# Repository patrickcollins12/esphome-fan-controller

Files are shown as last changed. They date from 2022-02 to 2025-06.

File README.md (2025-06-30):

# ESPHome Fan Controller

This project describes how to build a whisper quiet thermostat-controlled fan for cooling your media console, gaming cupboard or that dying star in your networking cabinet.

The software is ESPHome and Home Assistant. The hardware is an ESP32 with a regular 12v 120mm Computer Fan (PWM) and a Temperature Sensor (DHT11).

## Cost
The electronic parts are $29 USD including the ESP32. You will also need a multimeter.

## Motivation
My sons's Playstation 5 sits in our TV Console which runs hotter than Sol. Also in that Media Console is a Macmini, a Raspberry Pi and a few other devices. My wife likes to keep the door neat and closed, so it needs some cooling!

I used to have a thermostat that mindlessly flipped the fan on and off whenever the temperature crossed a threshold. Not great, the fan cycling was a mood killer on movie nights and dismally failed wife approval. Enter this smart thermostat: instead of brute-force toggling, it smoothly adjusts the 12V fan speed to maintain the perfect temperature. It’ll settle on just the right power level (say, 22% power) to keep things cool without the unnecessary drama.

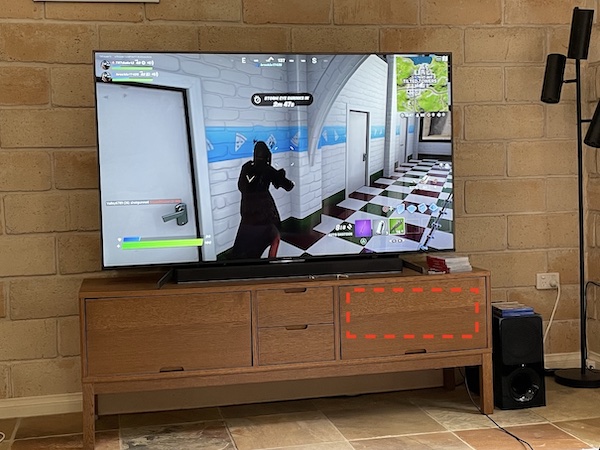
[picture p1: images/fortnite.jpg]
"closed cabinet"


## Features
The main features are:

- the **fan dynamically adjusts** it's speed based on the temperature sensor using a Process Control mechanism called PID
- **adjustable target temperature**. I currently target 30degC but maybe in winter I'll reduce it to 27.
- uses ESP32's Wifi to connect to Home Assistant for control and reporting
- the ESP32 is standalone and so the cooling function will continue to operate without Wifi. Doesn't need HomeAssistant or Wifi to operate. Wifi is only needed for setup, manual control and reporting.
- **no screen** is needed on the device itself, all management is done via Home Assistant
- my system uses two fans for extra cooling. Depending on how much air you need to draw through your enclosed space you could use 1, 2, 4, 10 .. n fans.
- one esp32 can control up to 10 independent enclosures each with separate temperature sensors and fans. You're only limited by the Amps of your 12v Power Bricks and the 10 pwm pins on your ESP32.
- **manual speed control** over ride if you don't want to use PID Control
- **no coding is needed**. Just some configuration in YAML files. In fact this repo only contains 1 file ``config-fan.yaml``.
- **No resistors, capacitors or difficult soldering needed**. The fan and the temperature sensor plug straight onto the pins of the ESP32. Although I did solder mount mine on a perfboard for cleanliness and put it in a case.

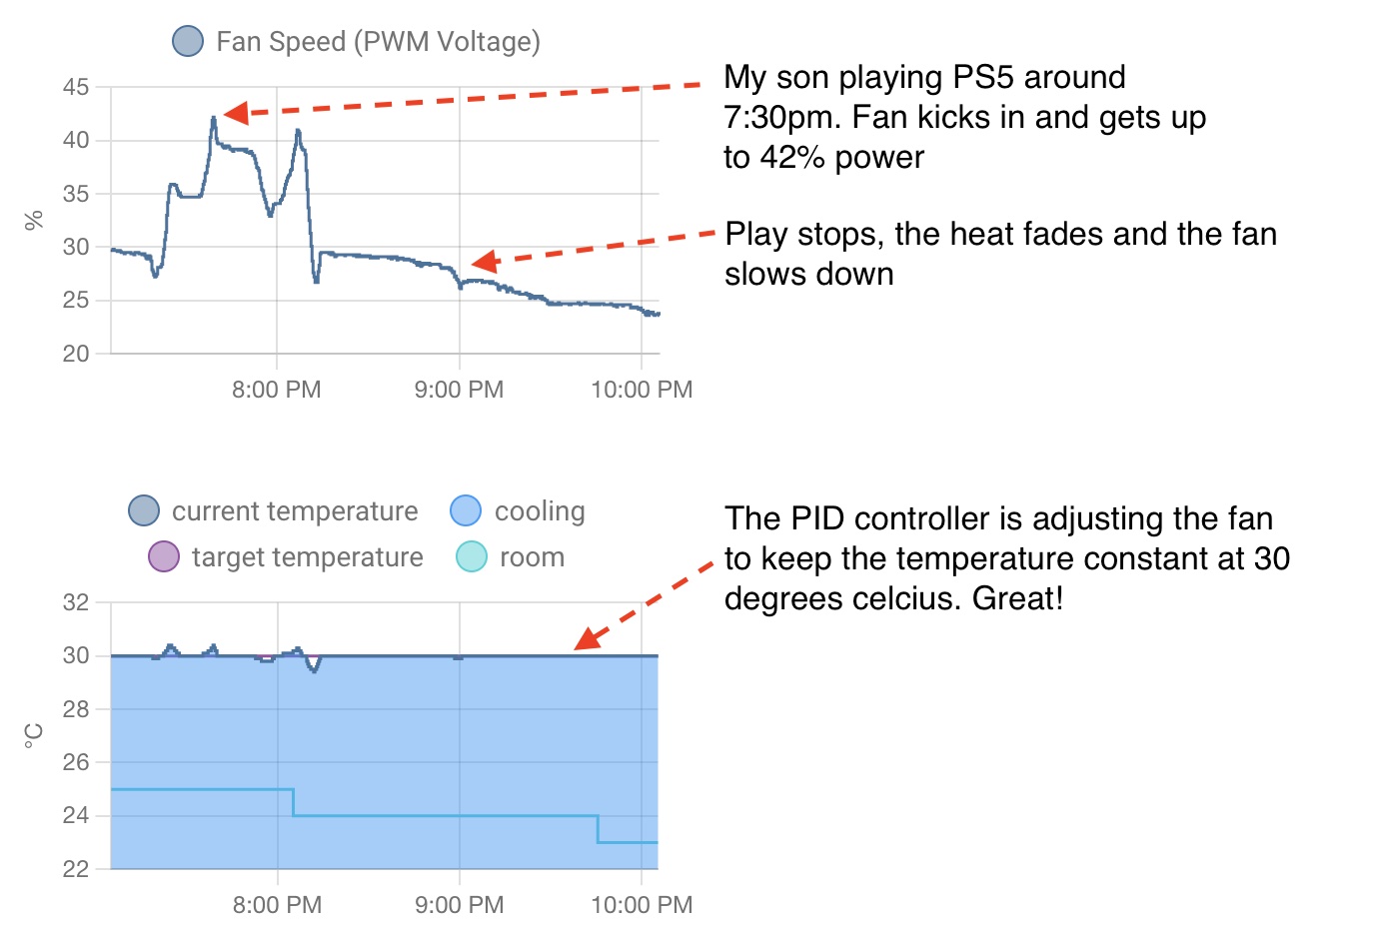
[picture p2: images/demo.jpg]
"graphs"


This is a screenshot from Home Assistant. I'll show you how to setup this dashboard.

## Visuals
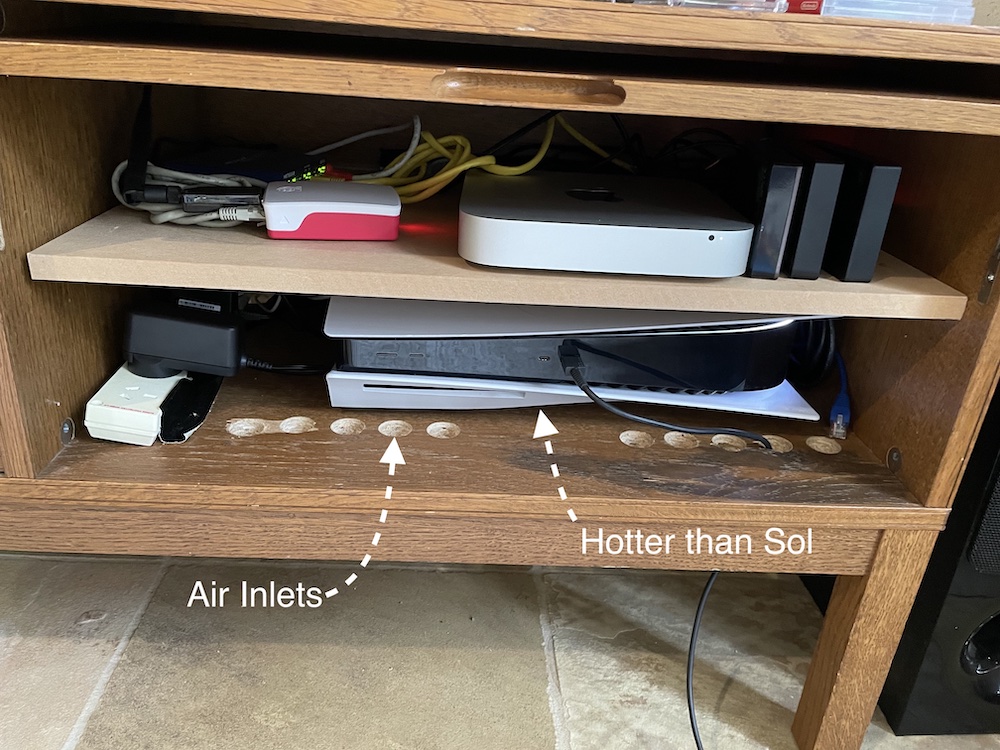
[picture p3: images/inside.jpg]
"inside cabinet"

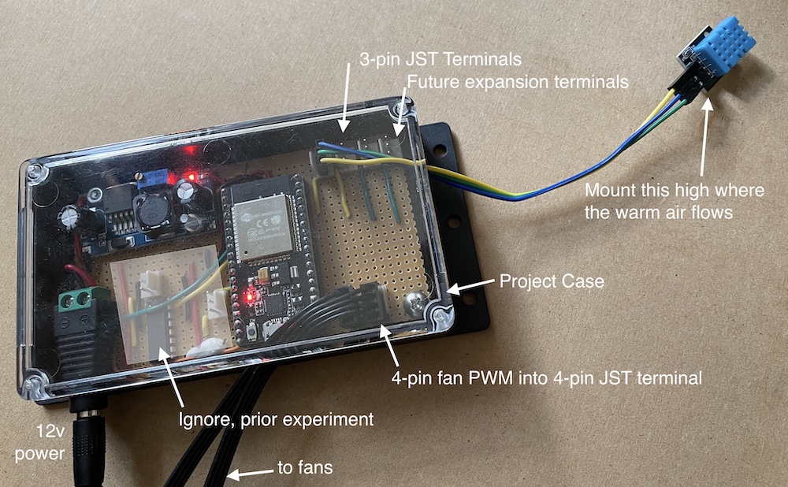
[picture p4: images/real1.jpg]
"controller"

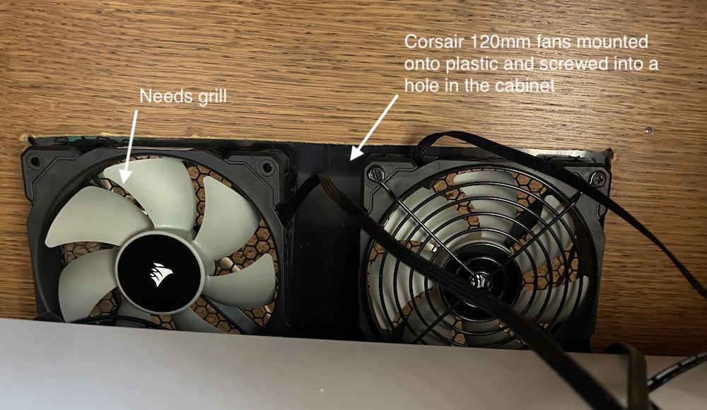
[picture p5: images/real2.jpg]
"fans"


## Examples from other users
https://github.com/patrickcollins12/esphome-fan-controller/issues/34

## Parts (~$29 USD)

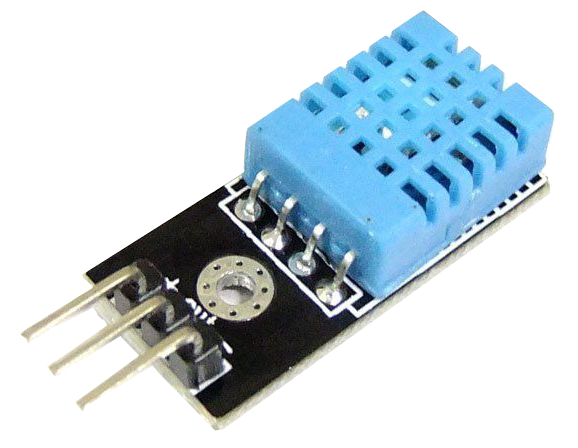
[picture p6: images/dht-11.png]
- **DHT11** - temperature and humidity sensor. I'm using the one on a board with 3-pins. Cost $0.20 USD<br>

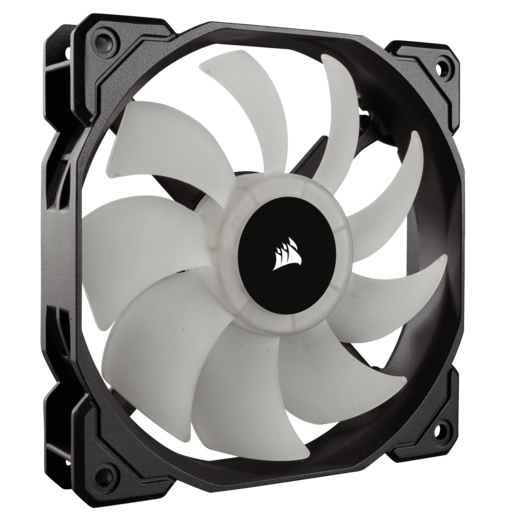
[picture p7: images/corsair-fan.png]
- **12v PWM 4-pin Computer Fan** - I'm using 2 x [120mm Corsair fans](https://www.corsair.com/us/en/Categories/Products/Fans/Magnetic-Levitation-Fans/ml-config/p/CO-9050039-WW). Any 12v PWM-controllable fan should work. Cost $8-$15 USD. I recommend getting high quality fans if you care about noise and need to move a lot of air<br>. 

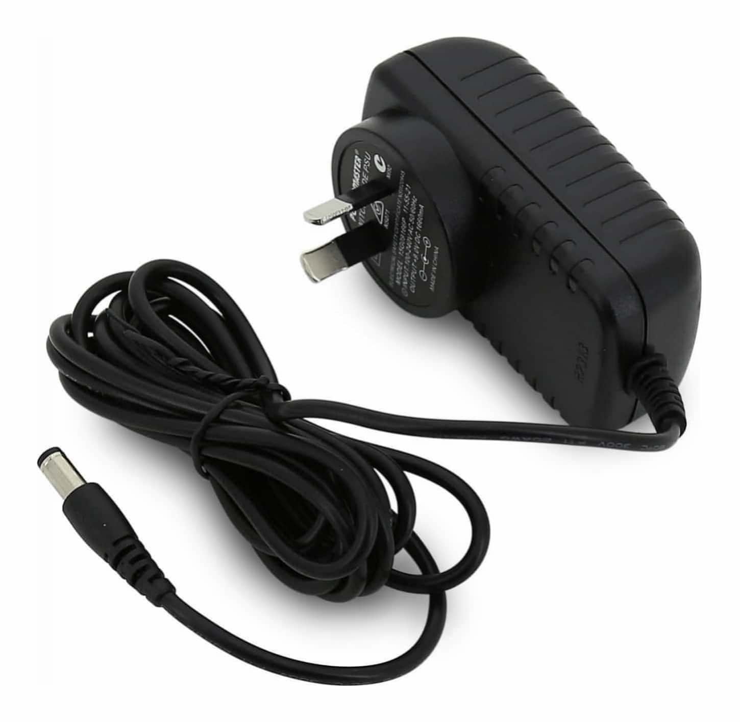
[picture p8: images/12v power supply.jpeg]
- **12v Power Adapter** - 1A or 2A should be fine depending on your fan's current draw. Cost $7 <br> 

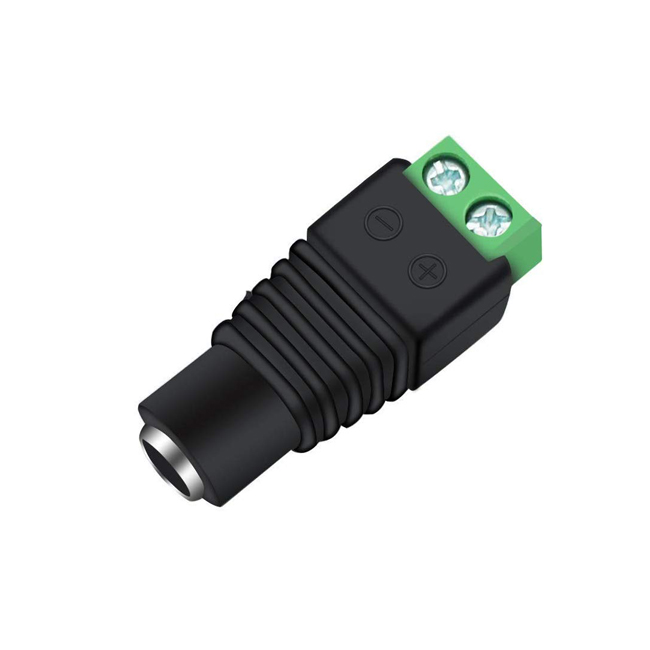
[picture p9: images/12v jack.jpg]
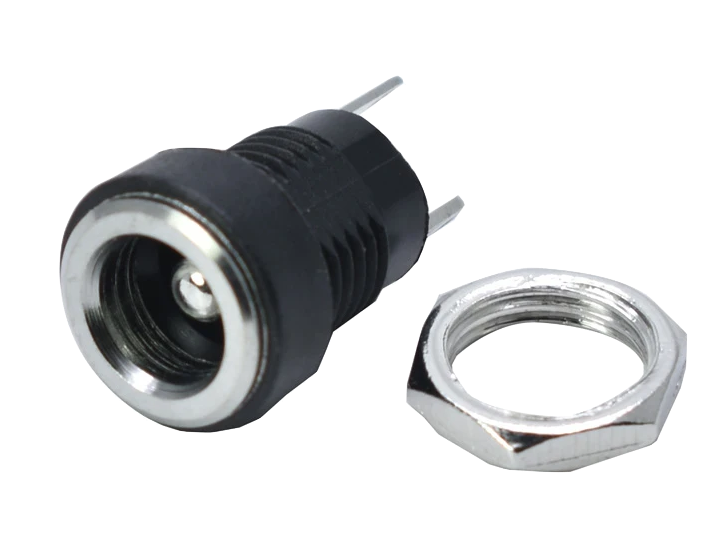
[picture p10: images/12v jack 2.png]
- **12v DC Female Jack** - with wire outlets. You can normally buy these with the Power Adapter<br> or  

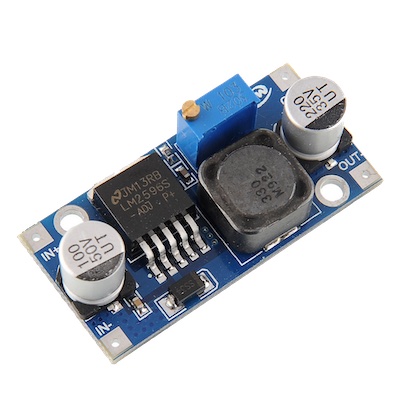
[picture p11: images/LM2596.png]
- **LM2596 Buck Converter** - to convert 12v down to 3.3v. Cost $0.21 each (normally in packs of 6-10)<br> 

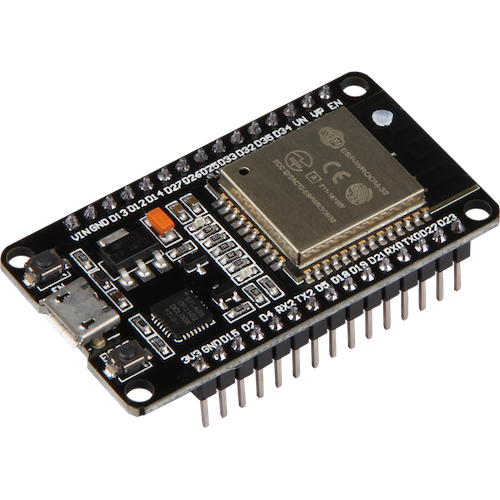
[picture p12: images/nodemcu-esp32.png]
- **ESP32**. You can use any ESP32. I'm using a NodeMCU compatible board. Mine cost $1.50 USD from Aliexpress. Note it [will also work on a Raspberry Pi Pico W](https://github.com/patrickcollins12/esphome-fan-controller/discussions/50).<br> 

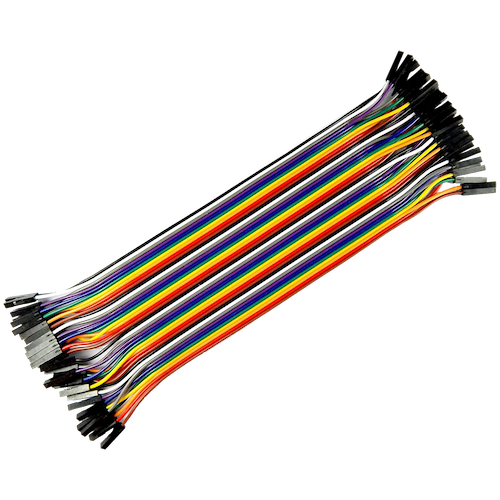
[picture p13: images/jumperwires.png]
- **Jumper wires**. Some jumper wires to connect the ESP32 to the various parts here. $1. <br>

You will also need a multimeter to adjust the output of the buck converter. Optionally, if you want to move this beyond a prototype you will need some soldering equipment and a 3d printer for a case or to buy a housing.

## Choosing a Good Fan
You need a 4-pin fan which has PWM. 3-pin fans aren't acceptable, they are just on/off with tachometer sensor.

As you'll see below, our fans are being powered by the PWM pin. Our expectation is that the fans stop spinning at 0% power. Some people have reported that some fans don't stop running at 0% power (or worse that they stop completely at 100% power which is weird). 

It appears that Corsair and Noctua fans behave as expected so you might want to stick with them.

However, if your fan does behave this way, you can use a MOSFET to turn it off. There are ([instructions here for how to do this](https://github.com/patrickcollins12/esphome-fan-controller/issues/17#issuecomment-1557136383)). Please post your progress to that issue.

## Wiring Diagram
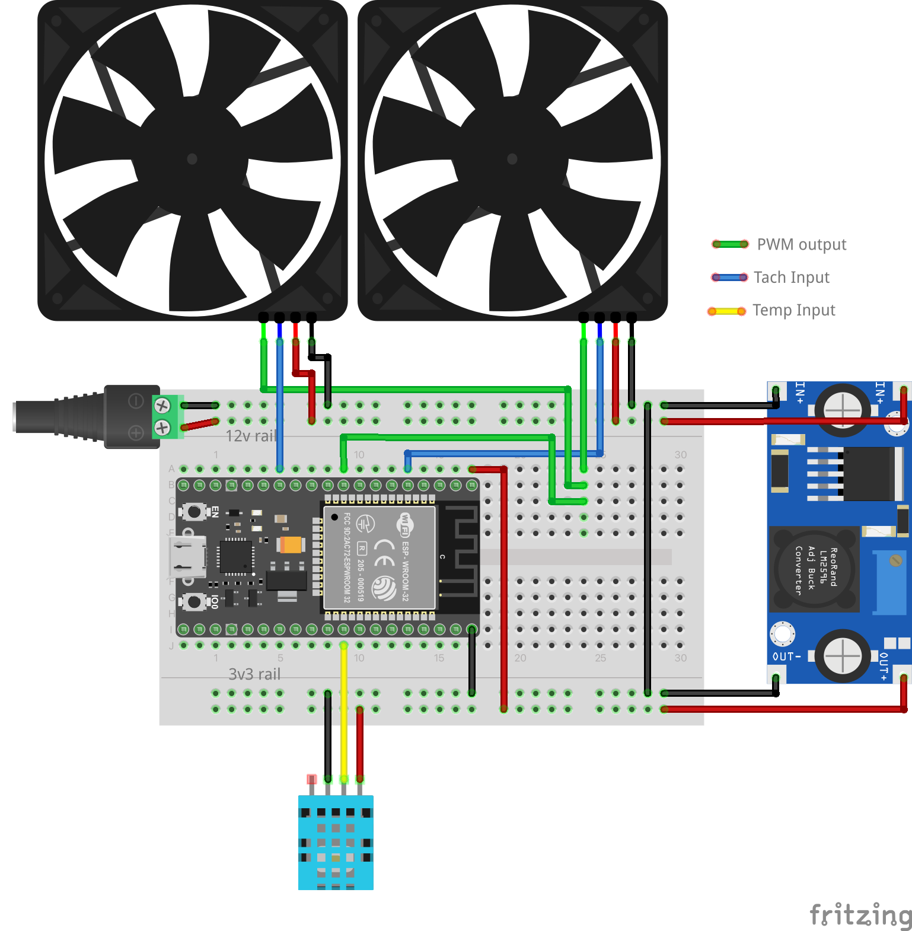
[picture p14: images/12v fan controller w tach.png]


Some important notes:
- connect the fan PWM pin to a PWM GPIO
- turn the knob on the buck converter with a screwdriver to make it output exactly 3.3v. You'll need a multimeter to measure that output.
- ensure the 12v and 3.3v grounds are connected together.
- the Blue line is the tachometer ("Tach") input pin. It is optional to connect this. You can connect this to a PWM input pin of your choice (GPIO25 in the example config) and it will send 1-2 pulses per full turn (depending on the fan). You can use this to monitor actual RPM of the fan and detect a fan defect, blocked rotor, etc. You will need one PWM input for each tach on each fan.
- you could easily skip the Buck converter and use two separate power sources 3.3v and 12v. 
- the fritzing diagram shows a 4-pin DHT-11, when in fact I have the simpler 3-pin version as shown in the parts list. The 4-pin version might need a pullup resistor, haven't tried it.

## Common Wiring Error - not joining grounds 

NOTE: if you don't join your 3.3v and 12v ground wires together your fan will keep spinning. At least 5 different builds have reported this issue. 

## Installing the software onto the ESP32

### Get this repo
Clone this github repository.
From the command line and then cd into the directory

```
git clone https://github.com/patrickcollins12/esphome-fan-controller.git
cd esphome-fan-controller
```

### Review the YAML and read the ESPHome docs.

Review the YAML file.

Ensure the pins are set correctly for the PWM Fan (ledc) and the DHT-11.

Review the instructions for [the ESPHome Climate Thermostat](https://esphome.io/components/climate/index.html), [ESPHome PID Climate Thermostat](https://esphome.io/components/climate/pid.html) and the [DHT-11 sensor](https://esphome.io/components/sensor/dht.html).

Change the device name from ``console-fan`` to whatever seems appropriate. You might want to change the yaml filename as well.

If you want to use a Raspberry Pi Pico instead of an ESP32, change the board and platform as well [according to this discussion](https://github.com/patrickcollins12/esphome-fan-controller/discussions/50).

### Setup your temperature sensor

Set the correct pin for your temp sensor. Note that the DHT11 sensor is setup to use an exponential moving average. Without this filter the PID controller reacts to every minor sensor movement. If you have a faster sensor like the BME260 you might need to tweak this filter.

```yaml
  # GET TEMP/HUMIDITY FROM DHT11
  - platform: dht
    pin: GPIO33
    temperature:
      name: "Temperature"
      id: console_fan_temperature
      accuracy_decimals: 3

      # If you don't smooth the temperature readings 
      # the PID controller over reacts to small changes.
      filters:
         - exponential_moving_average:  
             alpha: 0.1
             send_every: 1

```

(Some people [take an average of two temperature sensors](https://github.com/patrickcollins12/esphome-fan-controller/issues/5).)

### Setup your PWM fan

Make sure you connect your fan to a PWM capable GPIO. All ESP32 pins that can act as outputs can be used as PWM pins but GPIOs 34-39 can’t generate PWM.

Also note that my fans stop spinning below 13% power, so I set that as the minimum. I have a max power of 80% applied to the fans to make them wife-friendly. You might want to remove this minimum or maximum. 

```yaml
  - platform: ledc
    id: console_heat_speed
    pin: GPIO27

    # 25KHz is standard PWM PC fan frequency, minimises buzzing
    frequency: "25000 Hz"

    min_power: 13%
    max_power: 80%

```

### Setup your wifi details

``mv secrets-sample.yaml secrets.yaml``

Edit your wifi credentials in secrets.yaml. The .gitignore will prevent you accidentally uploading your wifi credentials to github.

### Install ESPHome

[Install ESPHome](https://esphome.io/guides/installing_esphome.html) according to the instructions on the ESPHome website.

I prefer command-line on Mac:
``pip3 install esphome``

Most people use the ESPHome that runs inside Home Assistant. You can use that too.

### Install to ESP32

Connect your ESP32 via USB to your computer, then upload the Firmware to the ESP32.

`` esphome run console-fan.yaml``

At this time if you've set the pins right, the sensor should be spitting out values and the PID can control the fan.

Success! 

```
% esphome logs console-fan.yaml
INFO Reading configuration console-fan.yaml...
INFO Starting log output from console-fan.local using esphome API
INFO Successfully connected to console-fan.local
...
[22:54:09][C][mdns:085]:   Hostname: console-fan
[22:54:09][C][homeassistant.text_sensor:023]: Homeassistant Text Sensor 'ha_kp'
[22:54:09][C][homeassistant.text_sensor:024]:   Entity ID: 'input_text.kp'
[22:54:10][C][homeassistant.text_sensor:023]: Homeassistant Text Sensor 'ha_ki'
[22:54:10][C][homeassistant.text_sensor:024]:   Entity ID: 'input_text.ki'
[22:54:10][C][homeassistant.text_sensor:023]: Homeassistant Text Sensor 'ha_kd'
[22:54:10][C][homeassistant.text_sensor:024]:   Entity ID: 'input_text.kd'
[22:54:10][D][dht:048]: Got Temperature=30.0°C Humidity=38.0%
[22:54:10][D][sensor:113]: 'Humidity': Sending state 38.00000 % with 0 decimals of accuracy
[22:54:11][D][dht:048]: Got Temperature=30.0°C Humidity=38.0%
[22:54:11][D][sensor:113]: 'Humidity': Sending state 38.00000 % with 0 decimals of accuracy
[22:54:12][D][dht:048]: Got Temperature=30.0°C Humidity=38.0%
[22:54:12][D][sensor:113]: 'Humidity': Sending state 38.00000 % with 0 decimals of accuracy
```

## Setup Home Assistant

If the above steps worked correctly, the device will be auto-discovered by Home Assistant. You will need to add the device.

Multiple sensors and switches are exposed by the ESPHome software.

You also need to setup the dashboard. I'll explain those two steps below.

## Setting up the Home Assistant Dashboard

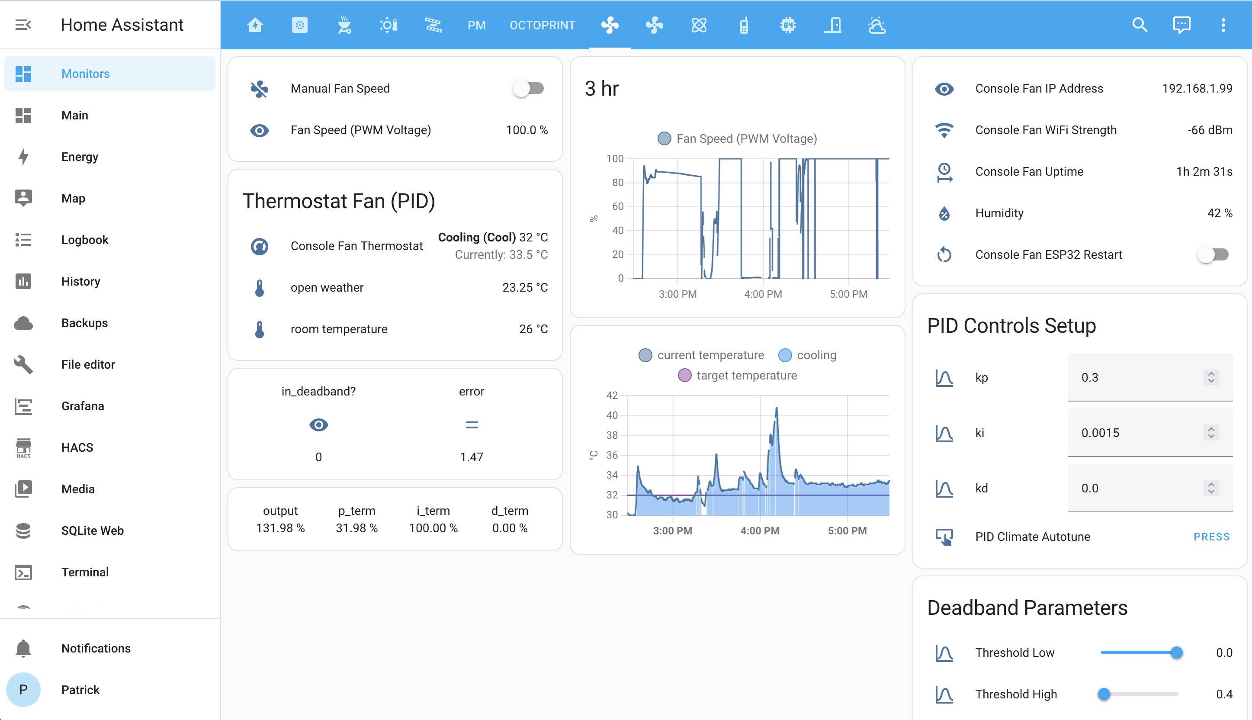
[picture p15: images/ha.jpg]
dashboard


Here is my full dashboard in Home Assistant.

For this full dashboard configuration, checkout ```lovelace-dashboard.yaml```

Let's go through this page section-by-section.

### The Primary Controls

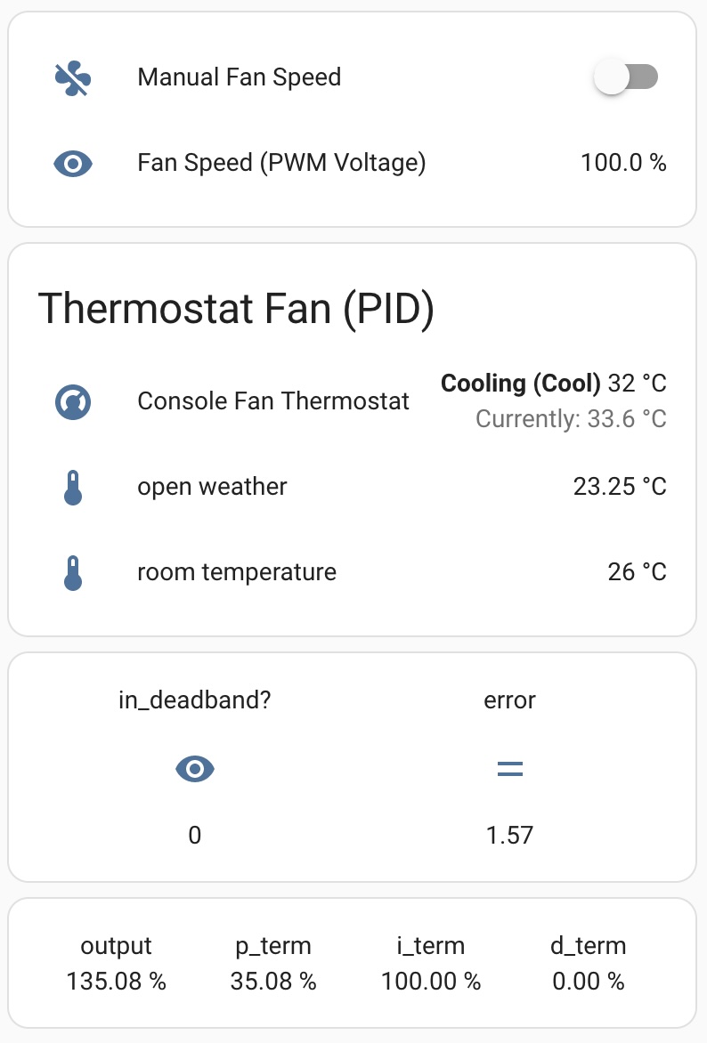
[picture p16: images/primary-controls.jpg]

 
```yaml
type: entities
entities:
  - entity: fan.manual_fan_speed
  - entity: sensor.fan_speed_pwm_voltage
```

- You can turn on  `manual fan speed` and use this fan control to adjust the speed manually. 

- The ``Fan Speed (PWM Voltage)`` is the % of voltage being sent out via PWM to the fan controller. At 100% it will be sending 12v, at 50% it will be sending 6v.

If `manual fan speed` is off, this next card stack will conditionally display.

```yaml
type: conditional
conditions:
  - condition: state
    entity: fan.manual_fan_speed
    state_not: 'on'
card:
  type: vertical-stack
  cards:
    - type: entities
      title: Thermostat Fan (PID)
      entities:
        - entity: climate.console_fan_thermostat
        - entity: sensor.openweathermap_temperature
          name: open weather
        - entity: sensor.contact_sensor_1_device_temperature
          name: room temperature
    - type: vertical-stack
      cards:
        - type: glance
          entities:
            - entity: sensor.console_fan_is_in_deadband
              name: in_deadband?
            - entity: sensor.console_fan_error_value
              name: error
              icon: mdi:equal
        - type: glance
          show_icon: false
          entities:
            - entity: sensor.console_fan_output_value
              name: output
            - entity: sensor.console_fan_p_term
              name: p_term
            - entity: sensor.console_fan_i_term
              name: i_term
            - entity: sensor.console_fan_d_term
              name: d_term
```

- The `Console Fan Thermostat` is a controllable thermostat, by clicking it you can alter the target temperature and turn the fan on/off. These changes will be persisted to flash on the ESP32.

- The `Open Weather` and `Room` temperatures are from other sensors in my house for reference.

- The ``kp, ki and kd`` inputs are exposed from the device. Your ESP32 will be automatically receiving changes to these values to control the behavior of the PID controller. While you could tune these from the config.yaml it requires a compile, upload and reboot cycle each time. This is inconvenient and best to tweak in real-time. We want to expose these 3 parameters to a Home Assistant dashboard.

### The Graphs

Add the fan speed and the thermostat to two separate graphs. I've also added my room temperature from a separate device for comparison.

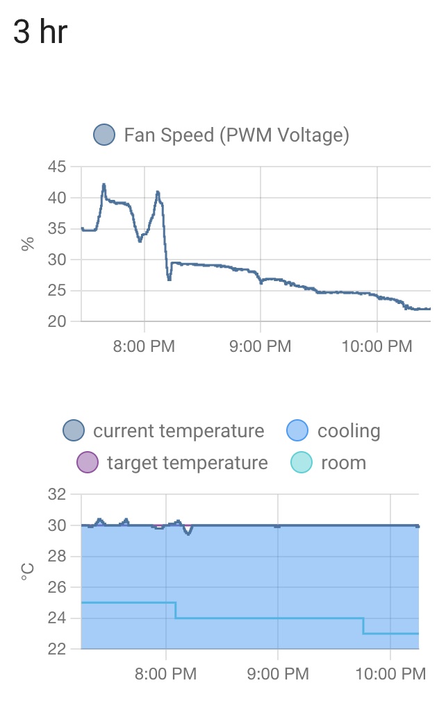
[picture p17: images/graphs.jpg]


```yaml
type: vertical-stack
title: 3 hr
cards:
  - type: history-graph
    entities:
      - entity: sensor.fan_speed_pwm_voltage
    hours_to_show: 3
    refresh_interval: 0
  - type: history-graph
    entities:
      - entity: climate.console_fan_thermostat
        name: ' '
      - entity: sensor.contact_sensor_1_temperature
        name: room
    hours_to_show: 3
    refresh_interval: 0
```

### Helpful Details - More Sensors and Switches

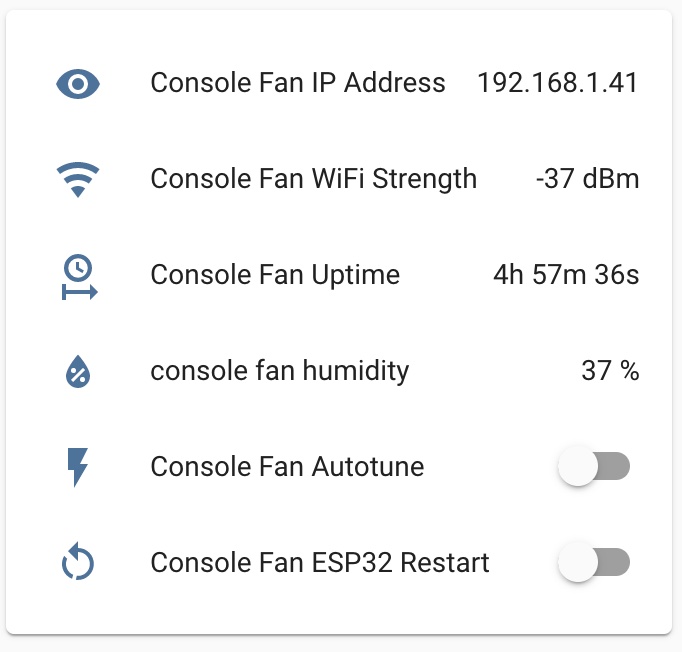
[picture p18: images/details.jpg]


This dashboard YAML exposes various sensors and switches from the ESP32.

```yaml
type: entities
entities:
  - entity: sensor.console_fan_ip_address
  - entity: sensor.console_fan_wifi_strength
  - entity: sensor.console_fan_uptime
  - entity: sensor.humidity
    name: console fan humidity
  - entity: switch.console_fan_autotune
  - entity: switch.console_fan_esp32_restart
```

- ``console_fan_autotune`` is a button which starts the [PID tuning](https://esphome.io/components/climate/pid.html#autotuning) process. I ended up abandoning this approach and manually tuning the PID.

- ``console_fan_esp32_restart`` restarts the ESP32 remotely.

### PID Parameters - setting the PID parameters from the frontend

This dashboard allows you to configure the PID parameters. See the next section for how to set these parameters.
This dashboard will conditionally disappear if `manual fan speed` control is `on`.

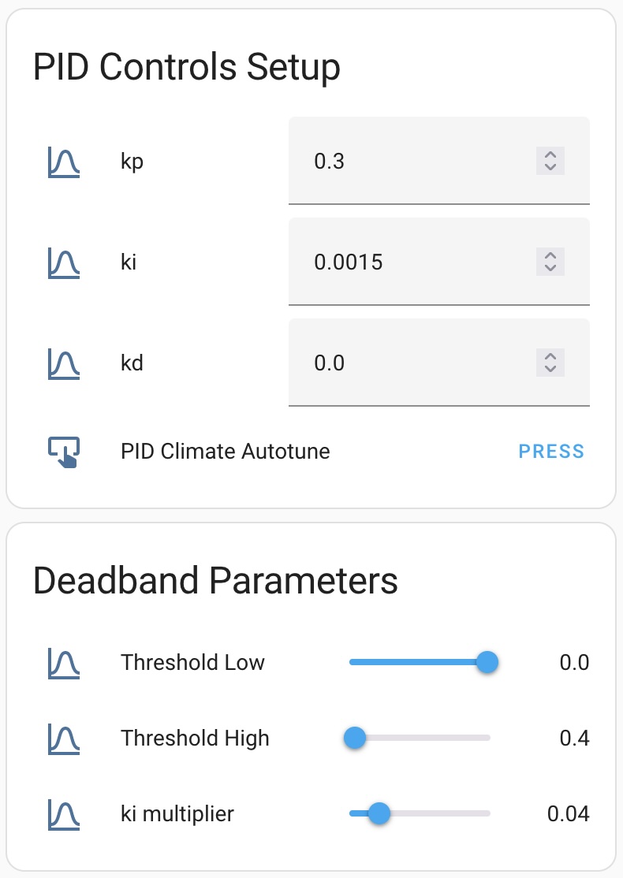
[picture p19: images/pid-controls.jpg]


```yaml
type: conditional
conditions:
  - condition: state
    entity: fan.manual_fan_speed
    state_not: 'on'
card:
  type: vertical-stack
  cards:
    - type: entities
      entities:
        - entity: number.kp
        - entity: number.ki
        - entity: number.kd
        - entity: button.pid_climate_autotune
      title: PID Controls Setup
    - type: entities
      entities:
        - entity: number.deadband_threshold_low
          name: Threshold Low
        - entity: number.deadband_threshold_high
          name: Threshold High
        - entity: number.deadband_ki_multiplier
          name: ki multiplier
      title: Deadband Parameters
```

## Tuning your fan - by configuring the PID Parameters

The thermostat is controlled using a standard Process Control system called a PID. 

In our system the goal of the PID control is to set the fan voltage (speed) to bring the temperature measured by the sensor to a target temperature (30degC).

Search the internet and you'll find many resources for setting up a PID Controller. There are a lot of resources for fast response systems like cruise control systems but not many for dealing with slow response cooling systems like this one.

The [ESPHome PID Climate](https://esphome.io/components/climate/pid.html) system that we're using here has some resources to explain how to tune the parameters. However, its autotune system didn't spit out useful results for me and I will explain how to manually get the right parameters. Your system will be different to mine and so your parameters will need to be slightly different. For instance, your cabinet will be a different size, I have two fans, you may only have one, etc.

There are only two parameters you will need to adjust: the kp and ki parameters. The kd parameter is not useful for us.

In my system the goal of tuning was to minimise aggressive changes to the fan (my wife complained she could hear the fan turning on and off). I don't mind the system drifting up to 2degC away from the target temporarily while it slowly reacts. A 7% drift (2degC/30degC) on some control systems could blow up a Nuclear plant or cause a Cruise Control system to crash into another car. But in our system a 7% short temperature drift is a fine tradeoff for quiet fans.

### Setting the kp (gain) parameter - how aggressively to cool?

KP is the main Gain. How aggressively will the fan respond to a small change in temperarature? Do you want the fan to go to 100% power in response to a 0.1degC change in temperature? In general my goal was to have the fan at 50% in response to a 1degC change in temperature, thus could normally stave off any further temperature rises, but if it the temperature did keep rising the fan will then climb to 100% power.

Using lower gain (0.1) (my preferred setting):
 - takes longer to cool down
 - is more likely to under react to fast temperature changes.
 - 2deg sharp spikes can occur before the system reacts
 - It can takes up to 10 minutes to fully close a 0.5degC gap.
 - but, it is much less likely to oscillate around the target temperature and cause the fan to turn on and off constantly.

Using higher gain (1.0):
 - responds quickly to changes in temperature
 - but, is more likely to oscillate and make the fan swing from 0% to 100% and back again as it tries to control the temperature. This means you can hear the fan trying to adjust.

### Setting the ki parameter - how long to adjust an offset?

``ki: 0.0009``

The ki parameter adjusts for temperature offset. Try setting ki to 0. Set your system initially with kp=0.1, ki=0 and kd=0. You'll find that the system operates with a constant delta/offset to the target temperature. The ki parameter adjusts for this.

1/ki is the seconds it should attempt to correct an offset. So 0.03 will adjust in 30seconds. 0.0009 will close a small temperature delta in 20 minutes. See a good description here https://blog.opticontrols.com/archives/344

Higher numbers like 0.03 will respond much quicker, but it also will cause a lot of noise and oscillation in the fan speed.

### Setting the kd parameter - predicting a change

The kd (D in PID) is meant to pre-react and backoff early. Small parameters can help overshoot but does create some fan noise and oscillation. The interwebs says that most (70%) of process controllers don't use the D and just a PI controller.

### Setting the deadband parameters - minimising changes once inside the zone

In my first contribution to ESPHome I added [Deadband to PID Climate](https://esphome.io/components/climate/pid.html#deadband-setup). Follow the instructions there to ensure that your fans stop oscillating once it reachs the correct target temperature.

### Tell me
I'm keen to hear what PID parameters works for your fan.

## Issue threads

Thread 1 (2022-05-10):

+/- in wiring

der--flo, 2022-05-10:
Hi, awesome little project !

But for me it looks like your schematic has a little error with plus and minus switched on the stepdown side and the bridge to ground on 3.3...
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
s

patrickcollins12, 2022-05-15:
Thanks! I'll correct it.

patrickcollins12, 2022-05-18:
Done, thanks.

Closed 2022-05-18.

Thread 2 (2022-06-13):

cool setup just what i was looking for but my fan does not shut off totally

dartfrogdk, 2022-06-13:
i set the fan at 0% and 50% but still it wont stop running totally, do you know what i can do

sophof, 2022-06-20:
I was working on the electrical setup of my own implementation of this this weekend and ran into the same problem, apparently some fans are just set up this way.
You have to use a relay to switch off the power entirely to the fan. I needed a level shifter as well to both up the PWM signal and the relay control signal to 5v. The next hurdle was that the fan then would run purely from the pwm output, so I also needed to switch of the level shifter output, luckily my level shifter allowed for control there too.

The end result (just for the fan for now, no PID control yet) looks as follows in the yaml:
``` yaml
output:
  - platform: gpio
    pin: GPIO26
    id: pwm_on
    inverted: true
  - platform: gpio
    pin: GPIO27
    id: fan_supply
  - platform: ledc
    pin: GPIO14
    frequency: 25000 Hz
    id: testfan

fan:
  - platform: speed
    output: testfan
    name: "Test Fan"
    on_turn_on:
      - output.turn_on: fan_supply
      - logger.log: "Power of Fan turned ON"
      - output.turn_on: pwm_on
      - logger.log: "PWM enabled"
    on_turn_off:
      - output.turn_off: fan_supply
      - logger.log: "Power of Fan turned OFF"
      - output.turn_off: pwm_on
      - logger.log: "PWM disabled"
```
With this the fan switches off at 0. 1% is then the startup RPM of my fan.

sophof, 2023-04-05:
It is hard to parse your comment this way, can you put your yaml in a code block? Just surround it with ``` before and after the code.

I changed my code a lot in the mean time and right now I have a much simpler version, where the fans are always on if my receiver is on in the TV cabinet that I'm cooling. Since I'm using two 140mm fans I literally don't hear them anyway on the lowest speed.

It simply imports a binary sensor from home assistant to check if the receiver is on, and if it is, switches the climate to COOL and turns on the relay and PWM. I also added a few simple buttons to be able to do it by hand (but I never have to use them anymore).
My code now looks as follows:
```
substitutions:
  friendly_name: Receiver Fan

esphome:
  name: tv-meubel-fan-links

esp32:
  board: esp32dev
  framework:
    type: arduino

# Enable logging
logger:

# Enable Home Assistant API
api:
  encryption:
    key: "redacted"

ota:
  password: "redacted"

wifi:
  ssid: !secret wifi_ssid
  password: !secret wifi_password
  power_save_mode: none
  fast_connect: true

dallas:
  - pin: 26
    update_interval: 10s

binary_sensor:
  - platform: homeassistant
    id: receiver_power
    entity_id: binary_sensor.receiver_power
    on_state:
      then:
        - script.execute: toggle_climate

script:
  - id: toggle_climate
    mode: restart
    then:
      if:
        condition:
          binary_sensor.is_on: receiver_power
        then:
          - climate.control:
              id: receiver_thermostat
              mode: "COOL"
        else:
          - delay: 5 min
          - climate.control:
              id: receiver_thermostat
              mode: "OFF"

sensor:
# ########################################################
# # START THE FAN CONTROLLER SETUP

  - platform: template
    name: $friendly_name p term
    id: p_term
    unit_of_measurement: "%"
    accuracy_decimals: 2

  - platform: template
    name: $friendly_name i term
    id: i_term
    unit_of_measurement: "%"
    accuracy_decimals: 2

  - platform: template
    name: $friendly_name d term
    id: d_term
    unit_of_measurement: "%"
    accuracy_decimals: 2

  - platform: template
    name: $friendly_name output value
    unit_of_measurement: "%"
    id: o_term
    accuracy_decimals: 2

  - platform: template
    name: $friendly_name error value
    id: e_term
    accuracy_decimals: 2

  - platform: dallas
    address: 0x940000000ca14e28
    name: "Receiver Temperature"
    id: receiver_temperature
    accuracy_decimals: 1
    filters:
    - filter_out: 85.0
    - throttle: 30s

  # Take the "COOL" value of the pid and send
  # it to the frontend to graph the output voltage
  - platform: pid
    name: "Fan Speed (PWM Voltage)"
    climate_id: receiver_thermostat
    type: COOL

output:
  - platform: ledc
    id: fan_speed
    pin: GPIO19
    frequency: "25000 Hz"

switch:
  - platform: gpio
    name: PWM gpio
    pin:
      number: GPIO18
      inverted: true
    id: pwm_on
  - platform: gpio
    name: Fan Power
    pin:
      number: GPIO03
    id: fan_supply

climate:
  - platform: pid
    name: "Receiver Fan Thermostat"
    id: receiver_thermostat
    sensor: receiver_temperature

    default_target_temperature: 33°C
    cool_output: fan_speed

    deadband_parameters:
      threshold_high: 0.4°C
      threshold_low: -1.0°C
      kp_multiplier: 0.0   # proportional gain turned off inside deadband
      ki_multiplier: 0.2  # integral accumulates at only 20% of normal ki
      kd_multiplier: 0.0   # derviative is turned off inside deadband
      deadband_output_averaging_samples: 10   # average the output over 10 samples within the deadband

    on_state:
      - sensor.template.publish:
          id: p_term
          state: !lambda 'return -id(receiver_thermostat).get_proportional_term() * 100.0;'
      - sensor.template.publish:
          id: i_term
          state: !lambda 'return -id(receiver_thermostat).get_integral_term()* 100.0;'
      - sensor.template.publish:
          id: d_term
          state: !lambda 'return -id(receiver_thermostat).get_derivative_term()* 100.0;'
      - sensor.template.publish:
          id: o_term
          state: !lambda 'return -id(receiver_thermostat).get_output_value()* 100.0;'
      - sensor.template.publish:
          id: e_term
          state: !lambda 'return -id(receiver_thermostat).get_error_value();'
      - if:
          condition:
            and:
              - lambda: 'return id(receiver_thermostat).mode == esphome::climate::ClimateMode::CLIMATE_MODE_OFF;'
              - switch.is_on: fan_supply
              - switch.is_on: pwm_on
          then:
            - switch.turn_off: fan_supply
            - switch.turn_off: pwm_on
            - logger.log: "Fan switched off"
      - if:
          condition:
            and:
              - lambda: 'return id(receiver_thermostat).mode != esphome::climate::ClimateMode::CLIMATE_MODE_OFF;'
              - switch.is_off: fan_supply
              - switch.is_off: pwm_on
          then:
            - switch.turn_on: fan_supply
            - switch.turn_on: pwm_on
            - logger.log: "Fan switched on"

    # The extents of the HA Thermostat
    visual:
      min_temperature: 20 °C
      max_temperature: 50 °C
      temperature_step: 1 °C

    # See the README for setting up these parameters.
    # These are over ridden by the number templates above.
    control_parameters:
      kp: 0.05
      ki: 0.0002
      kd: 0
      max_integral: 0.0
      output_averaging_samples: 4
```

Closed 2022-09-08.

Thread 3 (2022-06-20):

Fan Connector Type Doesn't Seem Right

gcortes, 2022-06-20:
I wanted to do this project to cool my electronics closet. I'm not an EE and haven't done electronics in ages so I could be wrong about this.

I bought the same Corsair fans as you specified (LM 120). In you image, you specify a JST connector. My research shows that the connector on the fan connects to a Molex 0470531000. It has a 2.54mm pitch as opposed to the 2.5mm of the JST connectors. There appear to be 4 different types, all 2.5mm. I'm going to go with the Molex as I'm going to build it on a solder breadboard.

The other confusing item is the pin out for the fan. Your wiring diagram shows using the first three pins. The third pin is Tach. In you description, you mention not using this. The web documentation I've found says pin 4 is control/PWM. I'm assuming that's the one you meant.

Thanks for posting this project. I've been thinking about how I could do something similar for quite some time. Now I have a solution.

patrickcollins12, 2022-07-08:
Sorry for the delay. I must have got lucky and got 2.54mm jst. There is no standards for jst but if you buy it from an arduino shop they normally fit the 2.54mm (.1”) standard perfboard pin spacing.

I can’t recall which pin is tach but I left it unwired. The fan accepts 3.3v or 5v as PWM data no problem.

Closed 2022-09-08.

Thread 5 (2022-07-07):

[Request] Possible to use two temperature sensors?

martijn-brant, 2022-07-07:
Thanks for this repo.. the code and schematics work great for me. My prototype is working great however I have a question.. is it possible to add another DHT temperature probe? My AV cabinets have two zones and I've added a fan in each. One is for the AV Receiver (always on when using TV) and the other is for gaming consoles (only on sometimes). I'd rather not build two separate fan controllers for two compartments. I don't mind both sides spinning faster when only one zone is needing more cooling (e.g. the gaming side being cooled even if there are no consoles active).

I had to reassign the DHT to GPIO23 on my nodemcu-32s board else it wouldn't work. PWM is on GPIO15. I've looking at the code as to what would be needed to support a 2nd DHT but the code is a bit too advanced for me. Ideally it would report two temperature values to Home Assistant as well and act on the worst one. But I would be more than pleased to get the worst value of the two as well. (one being 29c and the other 35c.. having it act like it's 35c and adjust fan accordingly).

Could you help with this? Many thanks.

patrickcollins12, 2022-07-08:
glad it worked for you!

Well you could easily run two separate systems off the one esp32: two pids, two dht, two fans. You would just copy all of those sections in the yaml file and give each a different name.

However, to answer your question directly. Yes you can take the max of two sensors to create a 3rd ”template” sensor. All three sensors will be visible to home assistant.

I’m not at my computer at the moment, so I can’t provide direct code.

This example creates a 3rd template sensor which is an average.

https://community.home-assistant.io/t/average-temperature-based-on-multiple-sensors/220781/3

to create a max instead the lambda is something like:

```yaml
lambda: |-
      return max(id(dht_temp_1).state, id(dht_temp_2).state);
```

let me know how you go.

martijn-brant, 2022-07-08:
Ah yes, great idea just to duplicate the YAML values for the sensors/outputs. I added an additional GPIO for extra PWM (Fan 2) and extra DHT11. Works like a charm. This gives me dual-zone option on a single Nodemcu. Thanks for your code and your reply.

B08Z, 2023-06-18:
> Ah yes, great idea just to duplicate the YAML values for the sensors/outputs. I added an additional GPIO for extra PWM (Fan 2) and extra DHT11. Works like a charm. This gives me dual-zone option on a single Nodemcu. Thanks for your code and your reply.

Hello,

Could you share you working yaml. I am about to start and may end up with 3 fans as they are a little small ( not ideal I know but got to work with what you got.)

Anyway if you could share how you did dual fans and dual dht temp that would be great

bartaspoz, 2023-07-22:
> Ah yes, great idea just to duplicate the YAML values for the sensors/outputs. I added an additional GPIO for extra PWM (Fan 2) and extra DHT11. Works like a charm. This gives me dual-zone option on a single Nodemcu. Thanks for your code and your reply.

Hey! I would be also interested in the code supporting two zones :) Many thanks!

martijn-brant, 2023-07-22:
Ah sorry I missed your first message @B08Z .. @bartaspoz here is the code:

`#based on https://github.com/patrickcollins12/esphome-fan-controller
substitutions:
  friendly_name: Console Fan

esphome:
  name: console-fan

esp32:
  board: nodemcu-32s
  framework:
    type: arduino

# Enable logging
logger:

# Enable Home Assistant API
api:

ota:
  password: "xxx"

wifi:
  ssid: !secret wifi_ssid
  password: !secret wifi_password

  # Enable fallback hotspot (captive portal) in case wifi connection fails
  ap:
    ssid: "Console-Fan Fallback Hotspot"
    password: "xxx"

captive_portal:

globals:
  - id: dhttemp
    type: float
    restore_value: yes
    initial_value: '0'

number:

  ## RECEIVE kp,ki and kd parameters from input_text.kx helpers in
  # Home Assistant. See the PID controller below
  # These helper values will get saved to flash thus permanently over-riding
  # the initial values set in the PID below.

  # KP
  - platform: template
    name: $friendly_name kp
    icon: mdi:chart-bell-curve
    restore_value: true
    min_value: 0
    max_value: 50
    step: 0.001
    set_action:
      lambda: |-
        // ESP_LOGI("main", "!!!!!! kp from boot %d", id("console_fan_kp") );
        // id(console_thermostat).set_kp( id("$friendly_name kp") );
        id(console_thermostat).set_kp( x );

  # KI
  - platform: template
    name: $friendly_name ki
    icon: mdi:chart-bell-curve
    restore_value: true
    min_value: 0
    max_value: 50
    step: 0.0001
    set_action:
      lambda: id(console_thermostat).set_ki( x );

  # KD
  - platform: template
    name: $friendly_name kd
    icon: mdi:chart-bell-curve
    restore_value: true
    min_value: -50
    max_value: 50
    step: 0.001
    set_action:
      lambda: id(console_thermostat).set_kd( x );

  # KP2
  - platform: template
    name: $friendly_name kp2
    icon: mdi:chart-bell-curve
    restore_value: true
    min_value: 0
    max_value: 50
    step: 0.001
    set_action:
      lambda: |-
        // ESP_LOGI("main", "!!!!!! kp from boot %d", id("console_fan_kp") );
        // id(console_thermostat).set_kp( id("$friendly_name kp") );
        id(console_thermostat2).set_kp( x );

  # KI2
  - platform: template
    name: $friendly_name ki2
    icon: mdi:chart-bell-curve
    restore_value: true
    min_value: 0
    max_value: 50
    step: 0.0001
    set_action:
      lambda: id(console_thermostat2).set_ki( x );

  # KD2
  - platform: template
    name: $friendly_name kd2
    icon: mdi:chart-bell-curve
    restore_value: true
    min_value: -50
    max_value: 50
    step: 0.001
    set_action:
      lambda: id(console_thermostat2).set_kd( x );

text_sensor:

  # Send IP Address
  - platform: wifi_info
    ip_address:
      name: $friendly_name IP Address

  # Send Uptime in raw seconds
  - platform: template
    name: $friendly_name Uptime
    id: uptime_human
    icon: mdi:clock-start

sensor:

  # Send WiFi signal strength & uptime to HA
  - platform: wifi_signal
    name: $friendly_name WiFi Strength
    update_interval: 60s

  # This is a bit of overkill. It sends a human readable
  # uptime string
  # 1h 41m 32s instead of 6092 seconds
  - platform: uptime
    name: $friendly_name Uptime
    id: uptime_sensor
    update_interval: 60s
    on_raw_value:
      then:
        - text_sensor.template.publish:
            id: uptime_human
            # Custom C++ code to generate the result
            state: !lambda |-
              int seconds = round(id(uptime_sensor).raw_state);
              int days = seconds / (24 * 3600);
              seconds = seconds % (24 * 3600);
              int hours = seconds / 3600;
              seconds = seconds % 3600;
              int minutes = seconds /  60;
              seconds = seconds % 60;
              return (
                (days ? to_string(days) + "d " : "") +
                (hours ? to_string(hours) + "h " : "") +
                (minutes ? to_string(minutes) + "m " : "") +
                (to_string(seconds) + "s")
              ).c_str();

########################################################
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
Bond246, 2023-09-05:
Hello,

i want to hijack this closed thread because i'm trying to do the same. The first step i've done was to copy the DHT sensor yaml-part, pasted it down below and changed the IDs and names.

But whatever i do the 2nd sensor is always "NA%". No values.
I've already tried different GPIO Inputs, used different sensors. Attached the working sensor to the 2nd GPIO and so much more.

What could be wrong?
Instead of the DHT11 i'm using DHT22 sensors for my project.

``` yaml
sensor:
  # GET TEMP/HUMIDITY FROM DHT22
  - platform: dht
    pin: GPIO18
    model: DHT22
    temperature:
      name: "Temperature Unten"
      id: console_fan_temperature_1
      accuracy_decimals: 3

      # If you don't smooth the temperature readings
      # the PID controller over reacts to small changes.
      filters:
         - exponential_moving_average:
             alpha: 0.1
             send_every: 1

    humidity:
      name: "Humidity Unten"
      id: console_fan_humidity_1

    # the DHT11 can only be read every 1s. Use 1.3s to be safe.
    update_interval: 1.3s

  # GET TEMP/HUMIDITY FROM DHT22
  - platform: dht
    pin: GPIO23
    model: DHT22
    temperature:
      name: "Temperature Oben"
      id: console_fan_temperature_2
      accuracy_decimals: 3

      # If you don't smooth the temperature readings
      # the PID controller over reacts to small changes.
      filters:
         - exponential_moving_average:
             alpha: 0.1
             send_every: 1

    humidity:
      name: "Humidity Oben"
      id: console_fan_humidity_2

    # the DHT11 can only be read every 1s. Use 1.3s to be safe.
    update_interval: 1.3s
```

Closed 2022-07-08.

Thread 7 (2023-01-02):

No longer able to compile.

prokyle123, 2023-01-02:
I was trying to change some of the code and whenever i try to upload to the esp i get the following error.. it happens on 2 different boards. i also would like to make another one but cant if it wont upload. could you provide any help? i love this project and i get ALOT of use out of it.

I think it happened after an update and i feel like a url or dependency is no longer available.im completely unsure,

Processing aquariumcooler (board: esp32dev; framework: arduino; platform: platformio/espressif32 @ 5.2.0)
--------------------------------------------------------------------------------
HARDWARE: ESP32 240MHz, 320KB RAM, 4MB Flash
 - toolchain-xtensa-esp32 @ 8.4.0+2021r2-patch3

warning: Calling missing SConscript without error is deprecated.
Transition by adding must_exist=False to SConscript calls.
Missing SConscript '/data/cache/platformio/packages/framework-arduinoespressif32/tools/platformio-build.py'
File "/data/cache/platformio/platforms/espressif32/builder/frameworks/arduino.py", line 41, in <module>
LDF: Library Dependency Finder -> https://bit.ly/configure-pio-ldf
Library Manager: Installing FS
Warning! Could not find the package with 'FS' requirements for your system 'linux_x86_64'
Library Manager: Installing Update
Warning! Could not find the package with 'Update' requirements for your system 'linux_x86_64'
Library Manager: Installing ESPmDNS
Warning! Could not find the package with 'ESPmDNS' requirements for your system 'linux_x86_64'
Dependency Graph
|-- AsyncTCP-esphome @ 1.2.2
|-- WiFi @ 1.2.7
|-- ESPAsyncWebServer-esphome @ 2.1.0
|   |-- AsyncTCP-esphome @ 1.2.2
|-- DNSServer @ 1.1.0
|-- noise-c @ 0.1.4
|   |-- libsodium @ 1.10018.1
Compiling /data/aquariumcooler/.pioenvs/aquariumcooler/src/esphome/components/adc/adc_sensor.cpp.o
Compiling /data/aquariumcooler/.pioenvs/aquariumcooler/src/esphome/components/api/api_connection.cpp.o
In file included from src/esphome/components/adc/adc_sensor.h:4,
                 from src/esphome/components/adc/adc_sensor.cpp:1:
src/esphome/core/hal.h:14:10: fatal error: esp_attr.h: No such file or directory

******************************************************************
* Looking for esp_attr.h dependency? Check our library registry!
*
* CLI  > platformio lib search "header:esp_attr.h"
* Web  > https://registry.platformio.org/search?q=header:esp_attr.h
*
******************************************************************

 #include <esp_attr.h>
          ^~~~~~~~~~~~
compilation terminated.
*** [/data/aquariumcooler/.pioenvs/aquariumcooler/src/esphome/components/adc/adc_sensor.cpp.o] Error 1
In file included from src/esphome/components/socket/socket.h:5,
                 from src/esphome/components/api/api_frame_helper.h:13,
                 from src/esphome/components/api/api_connection.h:3,
                 from src/esphome/components/api/api_connection.cpp:1:
src/esphome/components/socket/headers.h:116:10: fatal error: sys/ioctl.h: No such file or directory
 #include <sys/ioctl.h>
          ^~~~~~~~~~~~~
compilation terminated.
*** [/data/aquariumcooler/.pioenvs/aquariumcooler/src/esphome/components/api/api_connection.cpp.o] Error 1
========================== [FAILED] Took 1.99 seconds ==========================

TheDK, 2023-01-15:
Just compiled it on ESPHome 2022.12.3 without a problem...

patrickcollins12, 2023-01-17:
Great to hear. I suspect it was a broken platformio or esphome

prokyle123, 2023-01-17:
i fixed my issue by using the DEPRECATED version of esphome. Thank you.

Closed 2023-01-21.

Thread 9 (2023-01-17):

Cool project!

jazzmonger, 2023-01-17:
Nice job on this! I'm totally stealing your PID efforts for 2 of my projects.

The first (and easier) is for my solar battery heaters.  I just finished getting a dimmer circuit working for 4 heating pads.
https://diysolarforum.com/threads/new-battery-heater-controller-home-assistant-and-esphome.53665/
I just got the ESPHome file to compile with all your PID stuff and added all the sensors to home assistant.  It's late and I'll head to my shop in the AM to try and understand how this cool PID controller works.

The second, and far more advanced use case, is for my Smart Wood Pellet Stove project. I finally have victory over this pellet stove after a year of slogging it to make it actually smart with 685 lines of ESPHOME code to control every aspect of it.
https://github.com/jazzmonger/wood-stove-with-TYWE1S-Tuya-chip

My plan is to employ the PID component to control the  Auger feed motor control for the pellets to barely keep the stove lit so the house doesn't overheat and the stove doesn't have to cycle on and off, requiring constant relighting and burning out $50 igniters every few months. In the graph, you can see the fire burning and cooling and burning and cooling, etc, etc as pellets are added and then backed off.

The idea is to maintain a constant LOW target burn temp that I can set. Minimum  is about 190C, which I've found by trial and error and keeps the stove on. This barely keeps the pellets burning and minimal heat output, perfect as the weather gets gradually warmer outside. I'd increase that a bit when outside temps drop and the stove has to work harder to keep the room warm.
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

https://github.com/jazzmonger/wood-stove-with-TYWE1S-Tuya-chip/discussions/28

I'm pondering what params to play with to use for the PID control line.
I have a few options:
Auger on time ( this is tricky as too little and fire goes out, too much and u get smoke)
Auger off time - how long before more pellets are added
Stoking temp - how low the exhaust temp goes before manually stoking the fire w more pellets

I you have any thoughts on this after the dozens of hours you probably spent on figuring out the PID stuff, I'm all ears!

patrickcollins12, 2023-01-17:
Hey there, I've taken over ownership of the pid component in esphome.

I'm about to buy my first smoker so I'm interested in for you go.

A few things to look into:

If the auger is simply on or off, take a look at slowpwm which you can use to emulate quarter or half speed. PID climate can use slowpwm natively.

The auger is only one way to control the heat. Another way is by opening and closing an exhaust vent to control air flow. You could use a stepper motor.

It will be slow to get pid parameters from the pid autotune feature but it might be the best way.

jazzmonger, 2023-01-17:
well then!  You better make sure everything is in order on that component!  One complaint I have about the ESPHome docs is that there aren't any links to examples of projects using a component. This would help a great deal!

I don't have any options for controlling venting unfortunately. The only control I have is the auger motor.

are you on Discord?

Jeff

patrickcollins12, 2023-01-22:
Discord: pcollins12

Closed 2023-02-04.

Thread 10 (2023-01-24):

This is so cool! But...couple of questions?

ChirpyTurnip, 2023-01-24:
Hi,

I have this running to control three fans on my inverter. Soon I will expand to cover a second inverter with a second set of fans (once I move out of breadboard stage). You made it so super easy to get up and running!

Question 1:
The main issue with inverter cooling is that I need a responsive cooling system but one that is skewed - I need a fast(ish) response and the long slow tail....is this where kd comes in?

Question 2:
I have a DHT dangling over the back of the inverter radiator to read the air temperature, but really I need something better to read the radiator fin temperature directly, or a way of pushing the inverter internal temperature (which HA knows) to the fan controller...but with the option to still use DHT incase HA fails for some reason. That is, use inverter internal temp reading and if null revert to DHT temperature. Is this possible? if so how the heck could I pull that off?

Question 3:
I'd really like to bring in the tachometer data so that I can detect fan failure. I can do all the logic in HA/NodeRed, just need to plumb up the pins and get a reading....any tips? I've seen a few ways of doing it with resistors, logic level shifters, capacitors etc....but it seems a little complicated? From the looks of things I have exactly the same fans as you...  :-)

Thanks heaps!

CP.

DunklesKaltesNichts, 2023-01-25:
Q3:
The speed can also be read directly with an ESP.  i use the simple attached circuit for this, but with one change. my Lolin D32 has internal pullups, so the external 10k resistor is not needed.
for your board you have to check yourself which GPIO have a pullup or use the external resistor.

```
sensor:
# RpM Fans outward
  - platform: pulse_counter
    pin:
      number: GPIO13
      mode: INPUT_PULLUP  # activate internal pullup
    name: ${nodename}" RPM outward"
    unit_of_measurement: "UpM"
    accuracy_decimals: 0
    id: ${nodename}_rpm_outward
    update_interval: 5s
    filters:
      - multiply: 0.5    # 2 pulse per rotation
# RpM Fans inward
  - platform: pulse_counter
    pin:
      number: GPIO27
      mode: INPUT_PULLUP
    name: ${nodename}" RPM inward
    unit_of_measurement: "UpM"
    accuracy_decimals: 0
    id: ${nodename}_rpm_inward
    update_interval: 5s
    filters:
      - multiply: 0.5

```

Q2:
you should get the temperature from HA with the API to ESP, but I haven't dealt with that yet.
https://esphome.io/components/api.html
https://esphome.io/components/sensor/homeassistant.html
but the problem is then when the connection to HA is lost

in your case, i would probably rather replace the DHT with a Dalls DS18b20, which I would screw directly to the heatsink.
maybe with something like this: https://aixontec.com/Cable-fastening-clamp-according-to-DIN-72573-two-layer-galvanized-steel-5-mm-10PACK

for a slightly better reading, the sensor is also available without stainless steel housing.

the control runs through the ESP and with Dallas temperature sensor and HA only gives a warning when the temperature exceeds a certain value.

Q1:
i don't know.

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

ChirpyTurnip, 2023-01-28:
Most excellent! I have now hot both inverters with three fans each running. :-)

I have the DHT still in place as a backup but the cooling logic is running off the internal inverter temperature for now...I will look for a place to mount a thermocouple on the inverter but from what I can see without taking if off the wall there's not too many easy options...dangling it in space as with the DHT will not be as effective.

RPMs worked a treat too! A fun little project.

At present using KP of 0.1, KD and KI are both zero. Inverter heat is a bit chaotic as sun condition can cause wild fluctuations in generation and therefore heat output. So KP does a simple job...may add a little KD atcsomecstagecwhen I have more data. Initial testing shows the fans will knock 20-30°C off the running temperature.

Fans:
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

Controller:
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

The spaghetti:
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

HA (not running as night):
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

Thanks for your help and inspiration! Got me well and truly underway...

CP.

DunklesKaltesNichts, 2023-01-28:
can you show the code on how to get the temperature from the HA to the ESP?

ChirpyTurnip, 2023-01-29:
Sure thing! Code below. :-)

I do have a small section to define the "effective temperature" which is basically a 'best-of' the inverter internal or DHT temperature....that part needs a little more work when I get some more time. The external air temperature lags the internal temperature and is much lower - so I will need to fudge that (e.g. air temp + 20C to 'estimate' internal temperature) as I cannot drive the inverter set point temperature (based on internal temp) against the air temperature as the air is so much cooler. Either that or I need to create a second 'mode' - cool against internal temp, OR, cool against air temp. As it is just a backup in case HA goes away and I lose the internal temp data the first approach (+20C) seems easier.....but I've parked it for now until the weekend as I have some other things to do. :-)

```
substitutions:
  devicename: esp32-inverter-cooling
  friendly_name: Inverter Fan Control

esphome:
  name: $devicename

globals:
  - id: dhttemp
    type: float
    restore_value: yes
    initial_value: '0'

#########################
# ESP32 AND NETWORK SETUP

esp32:
  board: esp32dev
  framework:
    type: arduino

# pid climate log update is noisy, dial it back to warn
logger:
  level: DEBUG
  logs:
    climate: ERROR
    dht: WARN
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
patrickcollins12, 2023-01-31:
BTW those fan mounts like amazing. well done. space age.

ChirpyTurnip, 2023-01-31:
So the inverter has a temperature sensor and I use MODBUS to read this out
and give it to HA. This i can pass back to the esp32 so it can run to this
temperature as it's the best data I can get from the heart of the machine.

The inverter doesn't have it's own active cooling system - it has a passive
radiator/ heatsink on the back (between the inverter and the wall) and it
relies on passive air movement and the draft that's created as the hot air
rises. During peak production the temperature of the inverter went to over
70C which is bad for efficiency and not good for the life of the machine.
So adding some fans to draw air up and out makes the heatsink super
effective - the max temperature now is about 42C....30C less. :-)

I can't put a probe inside the inverter (void warranty, plus it's all solid
state electronics so don't want to mess with it) and there's not really
much room to neatly attach a probe to the heat sink either....but I can
dangle a DHT over the heatsink and measure the air temperature from the
rising warm air. There's a max of about a 15-18C temperature difference
between core temperature and air temperature when the fan is running.

I want this because if HA goes away (dead, crashed while I'm on holiday,
being rebuilt, etc) I still want the controlled cooling -  there'd be no
HA-based data feed of the internal temperature, but I can still get the DHT
temperature locally and I can run and control the fans with that... Meaning
the fans will stop when it's cool and work harder when it's hot (versus not
running at all or running at full speed).

I use the fan rpm data (or will when I get there) to detect fan or 12v PSU
failure, and if my ESP32 or 5v dies the fans will run at 100% (no PWM) but
HA can tell me it's gone offline (or, again, it will when I get there).

Make sense?

On Tue, 31 Jan 2023, 16:33 Patrick Collins, ***@***.***>
wrote:

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

ChirpyTurnip, 2023-01-31:
Not going to lie, a piece of scrap toe kick board from a kitchen cabinetry
install with the corners cut at an angle, and a bit of undercoat paint to
make it white again (good colour match). Little white brackets ($4 for 10)
from the local building/hardware store. Cheap and cheerful but works good!

On Tue, 31 Jan 2023, 16:39 Patrick Collins, ***@***.***>
wrote:

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

patrickcollins12, 2023-01-31:
> So the inverter has a temperature sensor and I use MODBUS to read this out and give it to HA. This i can pass back to the esp32 so it can run to this temperature as it's the best data I can get from the heart of the machine. The inverter doesn't have it's own active cooling system - it has a passive radiator/ heatsink on the back (between the inverter and the wall) and it relies on passive air movement and the draft that's created as the hot air rises. During peak production the temperature of the inverter went to over 70C which is bad for efficiency and not good for the life of the machine. So adding some fans to draw air up and out makes the heatsink super effective - the max temperature now is about 42C....30C less. :-) I can't put a probe inside the inverter (void warranty, plus it's all solid state electronics so don't want to mess with it) and there's not really much room to neatly attach a probe to the heat sink either....but I can dangle a DHT over the heatsink and measure the air temperature from the rising warm air. There's a max of about a 15-18C temperature difference between core temperature and air temperature when the fan is running. I want this because if HA goes away (dead, crashed while I'm on holiday, being rebuilt, etc) I still want the controlled cooling - there'd be no HA-based data feed of the internal temperature, but I can still get the DHT temperature locally and I can run and control the fans with that... Meaning the fans will stop when it's cool and work harder when it's hot (versus not running at all or running at full speed). I use the fan rpm data (or will when I get there) to detect fan or 12v PSU failure, and if my ESP32 or 5v dies the fans will run at 100% (no PWM) but HA can tell me it's gone offline (or, again, it will when I get there). Make sense?
> […](#)
> On Tue, 31 Jan 2023, 16:33 Patrick Collins, ***@***.***> wrote: why can't you put the sensor inside the inverter? Why does the inverter
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

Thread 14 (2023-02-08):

Problems using Dallas sensor

jazzmonger, 2023-02-08:
I have this controller working well on my Solar battery heater application.  I use it with a Pwm dimmer to control the heating pads and I use a temp sensor from the battery BMS software that is exposed via a homeassistant  sensor. It's all detailed in this Solar forum:

https://diysolarforum.com/threads/new-battery-heater-controller-home-assistant-and-esphome.53665/#post-685275

however, I have noticed that there are dropouts of that sensor when home assistant becomes unavailable for any reason which results in the battery either not being heated or being heated too much.  So I am trying to add a local Dallas temp probe that I can sandwich between the batteries and have a self contained system running completely in ESPHome on one chip.

![Uploading 033F3A39-1DD3-4D61-A328-BA5D7D38FBBD.jpeg…]()

The problem is whenever the Pwm dimmer is ON (even at 1%), the Dallas temp sensor throws "Scratch pad checksum invalid!" errors and can't be read.

I'm no stranger to this approach in ESPHome or these sensors.  I have several in use in my greenhouse and other areas. I've tried shielding the sensor wires, and even tried every available GPIO for the sensor and even watched the Dallas waveform on my scope when adjusting the pull-up resistor, all to no avail.

using a DHT type sensor isn't an option due to the way the batteries are mounted. It really needs to be a "probe" type sensor.

Any pointers or ideas to solve this are welcome!

DunklesKaltesNichts, 2023-02-08:
sensor maybe broken?
the wiring is definitely ok?

patrickcollins12, 2023-02-09:
Here is where that error is being thrown: https://github.com/esphome/esphome/blob/dev/esphome/components/dallas/dallas_component.cpp#L242

Looks like you can set logging to "very verbose" and get a little more information.

I've not used this sensor, so I can't help further. You could also try asking in the ESPHome Discord #hardware channel?

jazzmonger, 2023-02-09:
I just replaced the D1 Mini with an ESP32-S2 and the problem comp,Evelyn went away.  I'm almost ready to deploy this heater!

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

--

This message may contain confidential and/or privileged information. If
you are not the addressee or are not authorized to receive this for the 
addressee, you must not use, copy, disclose, or take any action based on 
this message or any information herein. If you have received this message 
in error, please advise the sender immediately by reply email and delete 
this message.

jazzmonger, 2023-02-09:
Success!
I have the temp probe in front of a halogen light which is the approximation of the solar battery pad heaters. The PWM waveform out of the EWP32 absolutely SUCKS but this is a known problem w/ PWM and AC dimmers. There's a ton of flicker, but I don't really think that's going to affect something passive like a pad heater.

The adjustments I have are:
kd - 0
ki - 0
kp - 0.3

Here's the temp graph:
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

what's curious is that the actual avg temp rides below the set temp once it settles.  Not that I think that will ultimately matter.

Thoughts?

patrickcollins12, 2023-02-10:
Yes the offset is because you need to set ki to some small value, try 0.001. The purpose of ki is to eliminate an offset like that. See the instructions where I outline how ki works.

Also try setting up the deadband to eliminate that oscillation you're seeing.

I'm not aware of PWM being flaky. Have you tried setting the output samples to smooth the output?

What is that graphing component you're using?

jazzmonger, 2023-02-10:
The Pwm issue was config related,  it literally took me 4 hours to cycle through all the permutations to find the right method/mode/int config.
```
output:
  - platform: ac_dimmer
    id: dimmer
    gate_pin: GPIO18
    zero_cross_pin:
      number: GPIO39
      mode: INPUT_PULLDOWN
    method: leading pulse
    init_with_half_cycle: true
```
But now it's finally acting like a true dimmer. I'll give the offset a go.  I read about the deadband, I'll implement that tomorrow.

I'm using Plotly for graphing,  it really slick.  A bit of a steep learning curve at first, and understanding the multiple Y axis', but worth the time investment.  You can code filters in real time AND see the results as you type.  Great for figuring out how to hard code them in ESPHome!
I built a wicked dashboard for my heavily modified pellet stove I flashed with ESPHome
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

jazzmonger, 2023-02-14:
Im struggling to figure out why I cant get rid of this temp offset:

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

I've tried ki values all the way up to 50!  no change.  I got rid of all oscillations by using KD=20.  No idea why.  but without it all I get is this:

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
kd = +20
ki = 50
kp = 0.42

I suppose I can just adjust the thermostat 1.2 degrees higher than I want it, but it would be nice to know why...

patrickcollins12, 2023-02-16:
That ki is far too large and will cause big oscillations.

Try turning off the kd temporarily.

Set ki to something small like ki: 0.0009

1/ki is the seconds it should attempt to correct an offset. So 0.03 will quickly adjust in 30seconds. 0.0009 will close a small temperature delta in 20 minutes. See a good description here https://blog.opticontrols.com/archives/344

Higher numbers like 0.03 will respond much quicker, but it also will cause a lot of noise and oscillation in the fan speed.

jazzmonger, 2023-02-26:
Ok, iI deployed it into the real world.  No matter what values I test with, I get about a 4 degree difference between Set temp and probe temp.  It's fine I just set the climate set temp 4 degrees higher than I want it.

It's a Complex graph, but all the elements are there and it works as expected.
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

This is before deployment
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

And this is the actual bms sensor inside the battery, reported by the BMS.  I deployed on 2/24 and raised the temp from 55F to 65F. Prior to 2/24, I had wide fluctuations both positive and negative depending on home assistant status (up/down) the Pi running the BMS, Wifi signal loss, etc, etc. Now everything is local within ESPHome and the PID controller.

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

you can see the on/off plug controlling the temp before 2/24.

I think I need to move the probe to inside one of the batteries. Right now it's sandwiched between the top and second one, so the reading location might not be perfect, but it's pretty good, so overall I'm happy with the result!

This all becomes ultra important in Dec/Jan ⛄️ when the temp drops into the teens and below zero F ❄️.  LifePO4 batteries self destruct if you charge the when they are less than 32F. And that's $15,000 worth of batteries I'm now protecting with a $2.00 Chinese ESP32-S2 😳

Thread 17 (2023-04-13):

Fan Corsair ML120

sobrarbe, 2023-04-13:
Hello, I just installed a Corsair ML120 fan as you say and it works well except for the one when it reaches the stop temperature and it keeps turning at 1400 RPM. Could you help me create a stop or what parameters can I change to make it stop?  the adjustments that you had at 13% the stop changed it to 0% but it continues turning.  could you help me??  thank you.

kaesebrot1199, 2023-04-28:
same here

DunklesKaltesNichts, 2023-04-28:
i tested it myself for fun. a 5 year old Corsair ML120 stops, but the one from November 22 keeps running.
Seems that Corsair has changed something.

you would have to buy fans with 0DB mode, the Corsair doesn't have that.

sobrarbe, 2023-04-28:
El 28 abr 2023 15:11, DunklesKaltesNichts ***@***.***> escribió:
i tested it myself for fun. a 5 year old Corsair ML120 stops, but the one from November 22 keeps running.
Seems that Corsair has changed something.
you would have to buy fans with 0DB mode, the Corsair doesn't have that.

—Reply to this email directly, view it on GitHub, or unsubscribe.You are receiving this because you authored the thread.Message ID: ***@***.***>

hello.  and could you put an IRF520 MOSFET inserted or is it not recommended?  And if it could be put, what would the yaml code look like?  Thank you so much

sobrarbe, 2023-04-28:
hello.  and could you put an IRF520 MOSFET inserted or is it not recommended?  And if it could be put, what would the yaml code look like?  Thank you so muchEl 28 abr 2023 15:11, DunklesKaltesNichts ***@***.***> escribió:
i tested it myself for fun. a 5 year old Corsair ML120 stops, but the one from November 22 keeps running.
Seems that Corsair has changed something.
you would have to buy fans with 0DB mode, the Corsair doesn't have that.

—Reply to this email directly, view it on GitHub, or unsubscribe.You are receiving this because you authored the thread.Message ID: ***@***.***>

sobrarbe, 2023-04-28:
hello.  and could you put an IRF520 MOSFET inserted or is it not recommended?  And if it could be put, what would the yaml code look like?  Thank you so much

patrickcollins12, 2023-04-30:
I'll update the instructions to include a mosfet and an off switch. A lot of people seem to need this.

sobrarbe, 2023-04-30:
thank you.  if you are so kind when i update it i commented here to see how to do it.

kaesebrot1199, 2023-05-02:
> i tested it myself for fun. a 5 year old Corsair ML120 stops, but the one from November 22 keeps running. Seems that Corsair has changed something.
>
> you would have to buy fans with 0DB mode, the Corsair doesn't have that.

Thanks for your testing. Can you possibly recommend a 0DB or 0rpm fan that might work. My Corsair fan still makes too many revolutions on the smallest setting.

DunklesKaltesNichts, 2023-05-02:
Arctic P12 PST 0dB

kaesebrot1199, 2023-05-05:
I did a new test with same new Corsair ML120, but now with an ESP8266 board. Now it runs as expected and the fan goes off below 13%.
There seems to be a difference between ESP32 (platform: ledc) and ESP8266 (platform: esp8266_pwm).

sobrarbe, 2023-05-05:
I have ordered a Corsair fan with a stop from 0 to 2000 RPM.  If it doesn't work, I'll do it as you say with an 8266. I also wanted to know if anyone could help me get the yaml to add an RGB light to this same project that includes the fan I bought.  I wanted that depending on the temperature detected by the temperature sensor, the RGB of the fan would turn on.  Red 40 to 50 °C Yellow 30 to 40 °C Blue 20 to 30 °C. Thus, by looking at the RGB light of the fan, I will know the temperature of the cabinet.  Thank you so much.

DunklesKaltesNichts, 2023-05-05:
i think you mean the Arctic 0DB. the fan has a 3 pin connector for the LED lighting. these are 5v, GND and the data line.

unfortunately, u do not know which protocol is needed. In the simplest case it is WS2812b LEDs. then it is easy and enough examples can be found in the net. you could try that first. Otherwise ask Arctic.

sobrarbe, 2023-05-05:
Thank you, I see that with the fan it will be complicated by the protocol you mention.  He still did what you say with a WS2812b led strip.  I'm new to ESP32 and I'm looking online to create the yaml and I'm not clear on how to add it to the yaml of this project with the WS2812b leds controlled by the temperature sensor that activates the fan.  Do you know of any tutorial that explains it well?  thank you.

sobrarbe, 2023-05-05:
I just found this documentation that can also be used for the fan with RGB light.  What do you think?  https://esphome.io/components/light/fastled.html

sobrarbe, 2023-05-15:
@kaesebrot1199  Hello.  You could pass the yaml configuration of this project to the Esp8266.  I'm trying and my Artic fan doesn't work and I don't know why.  Thank you.

sobrarbe, 2023-05-16:
@kaesebrot1199  Thank you very much for sharing your yaml. I just tried it but my fan still with 8266 board does not stop completely and I will have to integrate a MOSFET.  But it's not clear to me how to add it

kaesebrot1199, 2023-05-16:
> @kaesebrot1199 Thank you very much for sharing your yaml. I just tried it but my fan still with 8266 board does not stop completely and I will have to integrate a MOSFET. But it's not clear to me how to add it

I advise you to use a layout without MOSFET and find the right fan, which switches off at low PWM. You can see this in the datasheet of the fan.
Here for example the diagram of my Be Quiet fan: https://www.bequiet.com/admin/ImageServer.php?ID=ba45ba43151@be-quiet.net&.jpg
In the diagram you can see that the fan only turns on at 20% PWM. Not all PWM fans have this behavior. Maybe your Artic Fan cannot do that.

sobrarbe, 2023-05-29:
Hello @kaesebrot1199 , I am desperate with the fan that does not stop.  I just bought the be Quiet pro 4 as you recommend to test if it stops below 20% and nothing.  It keeps turning at low revs.  I test it with ESP32 and 8266 Board and the result is the same.  At the end I am going to put a MOSFET that @patrickcollins12 comments.  Waiting for the MOSFETs to arrive to test the configuration that it commands.

patrickcollins12, 2023-05-29:
Please confirm that your yaml also has min_power set to 0 in the ledc configuration

sobrarbe, 2023-05-30:
Yes, I have the minimum and maximum fan on and putting it from the minimum of 20% to 0% and it continues to run at 90 RPM.  I'll try the setup with the MOSFET you offer and comment.  I'm also thinking that it may be because of the type of ESP32 board that some manufacturer builds that does other output parameters?  or that doesn't matter.  Thanks for the help @patrickcollins12

sobrarbe, 2023-06-09:
Hello, today the MOSFETs have finally arrived and I put the programming that @ says and it works perfectly.  I wanted to know if you could help me one last time.  I have the RGB fan and I just realized that with the temperature it lights up in different colors depending on the temperature. It works very well for me and it looks very nice.  What I want to achieve is that at a certain time of the day, for example at night, the RGB LED turns off and that at a certain time in the morning it turns on and continues the cycle of color changes with the temperature.  Could that be done?  Thank you
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
bfleg, 2024-04-19:
Hi Bas, my circuit kinda ended up working but somewhere along the way, the fan stopped reporting the tach speed! Figured it was also “broken”.  Which for me was a problem, then my Mother-In-Law dumped her keys on my desk and when she scooped them up, along with a handful of jumper wires, I somehow lost ANOTHER ESP!! Bought a new couple of fans that are supposed to stop on zero, but have not revisited yet. Now winter is coming, for my use case, I will in the coming weeks…
But, I can confirm the circuit I posted above DOES work from a stop / start perspective…

BasJansen, 2024-04-19:
Thanks for the reply. Always blame your mother in law... I will use the scheme but what parts should I buy for Q22, Q23? Do you know what works? D16 is a diode and I have a few, is there something I should check with it.

patrickcollins12, 2024-04-20:
OK bummer I was hoping the zeromeanszero patch would have fixed this issue... it's clearly an issue with some fans. Would be happy to accept documentation if you get it working.

DeDiConsulting, 2024-06-05:
> Arctic P12 PST 0dB

bought one today, in the specs it has 300-2100 rpm
0rpm <5% PWW

in my config i have specified min_power: 0 and zero_means_zero.
with the switch off in HA, it still runs around 800 RPM ...

patrickcollins12, 2024-06-06:
I'll buy one to replicate and come up with a solution.

patrickcollins12, 2024-06-06:
Is this it? If not please send a link

https://www.ocgear.com.au/products/arctic-p12-pwm-pst

DeDiConsulting, 2024-06-06:
> I'll buy one to replicate and come up with a solution.

Great !

patrickcollins12, 2024-06-07:
I found that exact fan for $12AUD

patrickcollins12, 2024-06-07:
OK, so I have two fans, I unplugged one and plugged in the Arctic P12 Slim PWM PST.
It stopped spinning at 0 power for me.

https://github.com/patrickcollins12/esphome-fan-controller/assets/942296/28a32c41-11d0-4a82-bcf9-c58a802ff4bd

patrickcollins12, 2024-06-07:
@DeDiConsulting  I suspect there might be something wrong with your circuit. Like for instance, joining the two ground lines together. The 12v and 5v lines need to be earthed together. If that's not the issue can you share your circuit with a diagram and photo?

DeDiConsulting, 2024-06-07:
oh oooh ... i think i forgot to join the ground of the 12V & the 5V.
i will check this tomorrow ....

DeDiConsulting, 2024-06-08:
i can confirm, my bad.
as i was firing up the esp8266 from usb, from other power source, i forgot to join the grounds.
Once i did this, its working fine! doh... how could i forget that ....
Many thanks to everyone who jumped in right away

patrickcollins12, 2024-06-08:
I'm actually glad the solution was that simple because a lot of people have had this issue. I'm also glad that people don't have to add a mosfet because that impacts the simplicity of this project.

How can we adjust the instructions to be much clearer on this topic? Feel free to suggest or make a pull request.

BasJansen, 2024-06-10:
I have my Corsair fan now replaced with an Arctic above and it just works. So I guess some people still need a mosfet solution but you can always buy this affordable fan.

patrickcollins12, 2024-06-11:
@BasJansen any chance you can test both fans with and without the grounds connected?

BasJansen, 2024-06-11:
I tested both fans with and without ground connected. There seems to be no difference in behavior with or without.
Corsair fan: always spins, even when the esp32 did not totally boot. In the web interface I can switch it on and can speed it up or slow it down but not stop it.
Arctic fan: stays off until I switch it on in the web interface. In the web interface I can speed it up and down.

patrickcollins12, 2024-06-13:
We're all getting inconsistent results. My Corsair works fine. @DeDiConsulting arctic keeps spinning, but works when grounded properly.

BasJansen, 2024-06-13:
Strange maybe we can make a small fan only project. Get all the noise away
and try to get something consistent

On Thu, 13 Jun 2024, 15:00 Patrick Collins, ***@***.***>
wrote:

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

mainmind83, 2024-06-20:
664 RPM wich NXZT 140mm fan 🥴 I'll test with another fan...

corgan2222, 2024-06-25:
550RPM with NZXT 120mm. Have to buy the mosfet. :/

mainmind83, 2024-06-27:
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

adds a graphical scheme for electronics newbies :D

corgan2222, 2024-06-27:
Did I understand this correct?

Simplified
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

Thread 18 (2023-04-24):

One console with two separate connected fans

marxbenjamin, 2023-04-24:
Hello,

first of all respect and thanks for the guide! It was fun building it.
I connected two fans (one for in, one for out) to different pins. - I know I could have just soldered them together, but I didn't want to. - I can now control both separately and also get all sensor values output separately.

But I would like to specify only one target temperature value via the console and this should be given to both output IDs.

Is this possible? As far as I understand, I would have to specify both IDs of the "cool_output" here in the code. But I can't find the syntax for it.

```
climate:
  - platform: pid
    name: "Console Fan Thermostat Out"
    id: console_thermostat_out
    sensor: console_fan_temperature

    # It is summer right now, so 30c is a decent target.
    default_target_temperature: 30°C
    cool_output: console_fan_speed
```

DunklesKaltesNichts, 2023-04-24:
thats not possible.
but you can use my solution:

```
    id: ${nodename}_power_fans
# Merging GPIO26 and GPIO25, no hardware modification necessary
  - platform: template
    id: pwm_merge
    type: float
    write_action:
      - output.set_level:
          id: ${nodename}_pwm_inward
          level: !lambda return state;
      - output.set_level:
          id: ${nodename}_pwm_outward
          level: !lambda return state;
# PWM Fan inward
  - platform: ledc
    pin: GPIO26
    id: ${nodename}_pwm_inward
    frequency: 25khz
# PWM fan  outward
  - platform: ledc
    pin: GPIO25
    id: ${nodename}_pwm_outward
    frequency: 25khz
```

marxbenjamin, 2023-04-25:
Thanks very much! It works as expected! :)

Closed 2023-04-25.

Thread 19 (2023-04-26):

LED strip control

smathev, 2023-04-26:
Hi.

Really great project! It seems to be exactly what I'm looking for. I found it while searching for ways to make a 3D printer enclosure, like this: https://www.reddit.com/r/3Dprinting/comments/10io7st/how_the_ikea_platsa_3d_printer_enclosure_looks/

So, in the enclosure I would use your project to add a bit of active cooling / stabilize temperature. However, I would also like to add some lights in there - like the linked enclosure.

So, I figured the ESPHome would be able to control the lights, but to simplify the project I wanted to avoid also needing a 5V rail - So, I found these LED-strips: [WS2815](https://ardustore.dk/produkt/ws2815-5050-rgb-led-strip-12v-dc).

I was wondering if you knew whether it would be as simply as adding them to the 12V rail and adding them in the ESPHome component?

I realize this project isn't about lighting via ESPHome and it might not be needed in most peoples "media console housing", but I figured I would ask here since I consider my idea/thought an extension of your project.

Thank you for any input you could provide :)

patrickcollins12, 2023-04-29:
So I had the same need for my 3d Printer. If you're using Octoprint, I ended up using OctoRelay to plug a 12v light into the raspberry pi. The advantage of this is that you can control the light automatically when the 3d printer is running. To power the 12v lights I needed to use a mosfet.

That all being said, yes you could easily do the same from the ESP32:
ESPhome > ESP32 GPIO Out > Mosfet > 12v LEDs.

smathev, 2023-05-01:
Oh, ok.

So, I have no idea how I would add a Mosfest into this. I was looking at your schematics and thinking I just needed to run the 12V power to the LED strip, a ESP32 GPIO OUT to the controller of the 12V strip and the ground to a ground on the ESP32.

But, I'm guessing that's wrong from your description :)

So, I would need this: https://www.amazon.de/-/en/MOSFET-Switching-Voltage-Control-Transistor/dp/B08CDXCL83

And then connect the 12V and a GPIO out from the Arduino to the MOSFET and further on to this: https://ardustore.dk/produkt/ws2815-5050-rgb-led-strip-12v-dc
I'm really just guessing here.

 Would it be too big an ask for you to add your suggestion into the very clear schematic you have on your README from this product?

Again, I understand if this is way out of line, and I realize it's not part of your project at all. But any additional help would be appreciated :)

Closed 2023-06-02.

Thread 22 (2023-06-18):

Additional fans

B08Z, 2023-06-18:
Not sure this is an issue as I haven't actually started work on it. But I want to be able to connect 3 pwm fans and be able to read their rpm etc.

I have looked over the yaml and I assume I just copy the portion of code that specifies the ledc platform but change the gpio

If any one has a config for 2 or more fans that would be amazing.

B08Z, 2023-06-28:
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

Sorted it. Super easy.

Just wondering can I have variable PWM outputs. So rather than all 3 fans running the same they would have independent pwm input

patrickcollins12, 2023-06-29:
Yea you can. Put the pwm on a separate gpio. You’ll need3 temp sensors too though. Copy the climate yaml to create 3 pid climates with the temp sensors and 3 ledc’s, give them all unique ids and names. home assistant will then see 3 different climate controllers.

martinhoess, 2023-07-06:
Sorry for hijacking this but my question goes in the same direction.

Is the number of fans limited in any way other than by the power supply?
(Assuming they should all run at the same speed).

I have 5x3 12v 80mm and 2x 12v 120mm fans as ventilation for my small office  rack.
It would be really nice if I could control the fans dynamically via HA (depending on the office/rack temperature). Means the DHT11 I would not necessarily (only as a backup).

DunklesKaltesNichts, 2023-07-06:
the number of fans is not really limited. the number of independently controllable fans depends on the number of GPios.

 you can group all 80mm together and control the 120mm individually. it just depends on how you connect the PWM line of the fans.

martinhoess, 2023-07-07:
Thank you.

The plan was to make two units anyway (redundancy).
The 80mm are in groups of 5 (I wrote that the wrong way around). But they should all run the same speed anyway. But I will try that out soon :)

martinhoess, 2023-08-03:
I played around with it yesterday/today. Works wonderfully.

Additional fans work without problems, although I have now connected mine together as a chain and not each individually (in my case the fans should all run the same speed and they have an extra port to connect together).

The only thing I did different is, I left out the buck converter, this ESP board (not all) can be directly powered by VIN with 7-12 volts so you can use the 12V directly and the temperature sensor is powered by the 3V3 from the board.

And the DHT11 I replaced by a DHT22 because the DHT11 has only an accuracy of +-2 degrees (the DHT11 should be banned, the price difference is so minimal that it has no reason to exist).

martinhoess, 2023-08-23:
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

So, here is my attempt.

3D printed enclosure. Two with DHT22 instead of DHT11 and two with Dallas DS18B20 (because the probe has a long cable and is easier to attach somewhere). And as mentioned above I left out the step down because this board can work with 12V and provides 3V for the probe. On each box there are 5x80mm fans (daisy chained).

I still have to make the integration/display in HA nicer and also watchdog if one of the boxes should fail. The nice thing is that the fans work even if the ESP should not respond / be broken.

Thanks to @patrickcollins12 for the groundwork and creation of this project.

patrickcollins12, 2023-08-23:
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

This is my fan speed and cabinet climate over the last few hours. Doing it's job well.

cschillings, 2024-07-11:
How can i configure 2 fans to act like 1?
Same, RPM at same moment from the same temperature sensor.

Closed 2025-04-02.

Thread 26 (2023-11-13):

constantly reboots

Bond246, 2023-11-13:
Hello Patrick,

thanks for that repo. It is perfect for my need to cool the technic cupboard for DSL Router, NAS and these things in my livingroom.

To customize the project for my need without homeassistant but with node-red i disabled the HA API and enabled MQTT. I tried to add a 2nd temperature sensor but whatever i did it never had a value. So trying differenz GPIOs Pins, changing the sensor or add a pullup resistance it never worked. But thats not the question.

I think, in general, i havn't changed alot in your code but the scetch is never stable. Sometimes the ESP32 is running for 10 hours, sometimes only for 15min.
The reset reason is always `Software Reset CPU`

Any ideas what the problem could be or how to debug it?

Thanks

patrickcollins12, 2023-11-14:
Does the second sensor work if you swap it into 1st position? Determine if the sensor is working first or if it is a software issue.

I haven't tried mqtt on the device but it should work... seems like an out of memory error. Can you post the logs just prior to failure?

Get the logs via:

$ esphome logs fan.yaml

Feel free to post the yaml here too.

Bond246, 2023-11-16:
Hello patrick,

i've reduced the logs drastically to reduce the systemload which seemed to has an effect on the boot-cycle problem. So i have the same theory that either cpu or memory are being overloaded but i havn't found a way to get statistics about that from the esp32.

This is my configuration:
```yaml
substitutions:
  friendly_name: Serverschrank Fan

esphome:
  name: server-rack-fan

# Throttle writing parameters to the internal flash memory to reduce ESP memory wear / degradation
preferences:
  flash_write_interval: 15min

#########################
# ESP32 AND NETWORK SETUP

esp32:
  board: nodemcu-32s
  framework:
    type: arduino

# pid climate log update is noisy, dial it back to warn
logger:
  level: DEBUG
  logs:
    climate: ERROR
    sensor: ERROR
    text_sensor: ERROR
    dht: ERROR
    pulse_counter: ERROR

debug:
  update_interval: 5s

# default HA integration, OTA updater and backup http web portal
# api:
ota:
wifi:

  # Read the wifi/pass from secrets.yaml:
  # wifi_ssid: "My Wifi XX"
  # wifi_password: "XXXXXXX"
  ssid: !secret wifi_ssid
  password: !secret wifi_password

web_server:
  port: 80

mqtt:
  broker: broker
  discovery: false
  username: !secret mqtt_user
  password: !secret mqtt_password

number:

  ## OPTIONAL:
  # RECEIVE KP, KI and KD parameters from input_text.kx helpers in
  # Home Assistant. See the PID controller below
  # These helper values will get saved to flash thus permanently over-riding
  # the initial values set in the PID below.

  # KP
  - platform: template
    name: kp
    icon: mdi:chart-bell-curve
    restore_value: true
    initial_value: 0.3
    min_value: 0
    max_value: 50
    step: 0.001
    set_action:
      lambda: |-
        id(console_thermostat).set_kp( x );

  # KI
  - platform: template
    name: ki
    icon: mdi:chart-bell-curve
    restore_value: true
    initial_value: 0.0015
    min_value: 0
    max_value: 50
    step: 0.0001
    set_action:
      lambda: id(console_thermostat).set_ki( x );

  # KD
  - platform: template
    name: kd
    icon: mdi:chart-bell-curve
    restore_value: true
    initial_value: 0.0
    min_value: -50
    max_value: 50
    step: 0.001
    set_action:
      lambda: id(console_thermostat).set_kd( x );

  # Set threshold low
  - platform: template
    name: Deadband Threshold Low
    icon: mdi:chart-bell-curve
    restore_value: true
    initial_value: -1.0
    min_value: -20
    max_value: 0
    step: 0.1
    set_action:
      lambda: id(console_thermostat).set_threshold_low( x );

  # Set threshold high
  - platform: template
    name: Deadband Threshold High
    icon: mdi:chart-bell-curve
    restore_value: true
    initial_value: 0.4
    min_value: 0
    max_value: 20
    step: 0.1
    set_action:
      lambda: id(console_thermostat).set_threshold_high( x );

  # Set ki multiplier
  - platform: template
    name: Deadband ki Multiplier
    icon: mdi:chart-bell-curve
    restore_value: true
    initial_value: 0.04
    min_value: 0
    max_value: .2
    step: 0.01
    set_action:
      lambda: id(console_thermostat).set_ki_multiplier( x );

text_sensor:

  # Send IP Address
  - platform: wifi_info
    ip_address:
      name: $friendly_name IP Address

  # Send Uptime in raw seconds
  - platform: template
    name: $friendly_name Uptime
    id: uptime_human
    icon: mdi:clock-start

  - platform: debug
    device:
      name: "Device Info"
    reset_reason:
      name: "Reset Reason"

sensor:

  # Send WiFi signal strength & uptime to HA
  - platform: wifi_signal
    name: $friendly_name WiFi Strength
    update_interval: 60s

  # This is a bit of overkill. It sends a human readable
  # uptime string 1h 41m 32s instead of 6092 seconds
  - platform: uptime
    name: $friendly_name Uptime
    id: uptime_sensor
    update_interval: 30s
    on_raw_value:
      then:
        - text_sensor.template.publish:
            id: uptime_human
            # Custom C++ code to generate the result
            state: !lambda |-
              int seconds = round(id(uptime_sensor).raw_state);
              int days = seconds / (24 * 3600);
              seconds = seconds % (24 * 3600);
              int hours = seconds / 3600;
              seconds = seconds % 3600;
              int minutes = seconds /  60;
              seconds = seconds % 60;
              return (
                (days ? to_string(days) + "d " : "") +
                (hours ? to_string(hours) + "h " : "") +
                (minutes ? to_string(minutes) + "m " : "") +
                (to_string(seconds) + "s")
              ).c_str();

  # Read the Tacho PIN and show measured RPM as a sensor (only with 4-pin PWM fans!)

  - platform: pulse_counter
    pin:
      number: GPIO18   # Connect to any input PIN on the ESP
      mode: INPUT_PULLUP
    unit_of_measurement: 'RPM'
    id: fan_speed_1
    name: $friendly_name Fan Speed IN
    accuracy_decimals: 0
    filters:
      - multiply: 0.5  # Depending on how many pulses the fan sends per round - should be 0.5 or 1 - try...

  - platform: pulse_counter
    pin:
      number: GPIO19   # Connect to any input PIN on the ESP
      mode: INPUT_PULLUP
    unit_of_measurement: 'RPM'
    id: fan_speed_2
    name: $friendly_name Fan Speed OUT
    accuracy_decimals: 0
    filters:
      - multiply: 0.5  # Depending on how many pulses the fan sends per round - should be 0.5 or 1 - try...

########################################################
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
patrickcollins12, 2023-11-17:
Try disabling components, in particular the web server which is resource intensive.

If you disable ota you would also free up resources.

Start disabling some of the components I setup for debug. All of the components which send values back. They're technically only needed for debug anyway.

What kind of esp32 are you running? Different models have different ram.

patrickcollins12, 2023-11-17:
Also, is there a reason you need Mqtt rather than the HA api? The latter is more suitable and compact if the data is going to end up in HA anyway.

Bond246, 2023-11-18:
Thanks for your replay,

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

First step of integration was just to get a temperature-value. Next step would had been to use an average of both values as input for the PID. But i never get a value. Always just %NaN... I tried it with and without the pullup without any difference. The system is already integrated into its place so actually i don't have plans to add the 2nd sensor again. And in general it works well with one sensor.

My board is a DEBO JT ESP32 with Tensilica LX6 Dual-Core, 512kB SRAM and 4096MB ROM.
https://www.reichelt.de/nodemcu-esp32-wifi-und-bluetooth-modul-debo-jt-esp32-p219897.html?search=DEBO+JT+ESP32
I will try to disable some components as suggested. How can i reboot the chip when i disabled the webserver? Actually i'm doing a POST request on /switch/serverschrank_fan_esp32_restart/turn_on

> Also, is there a reason you need Mqtt rather than the HA api? The latter is more suitable and compact if the data is going to end up in HA anyway.

I don't have HA in my home-automation setup. I'm doing everything with Node-RED. All HA integration i found for Node-RED are really bad.

patrickcollins12, 2023-11-20:
Well the web server is very large and I've seen others having memory issues with it. So I suspect that is your problem. Try disabling it. If that solves the issue, maybe there is another solution for remote reboot, like mqtt.

Bond246, 2023-11-20:
Thanks so far.

I've tested another esphome package for Node-RED that uses the api. But it seems to that the connection is not stable and i get a lot of reconnects on the API.
In parallel i disabled the webinterface. Both options didn't changed anything.

So the next round:
- update all dependencies
- disable API
- disable webinterface
- disable number.platform.template: kp, ki, kd

Now i need to wait another day (or two) to see how stable it is.

Next step would be to switch from mqtt to api which means no mqtt but api. Last test was mqtt and api in parallel.

Bond246, 2023-11-20:
I've seen this option but acutally the reboots came later than 15min. So this is not the problem in general but maybe a side-effect.

If the problem stil exists with my acutal configuration i will switch from mqtt to api and will test this again.
Thanks.

DunklesKaltesNichts, 2023-11-20:
If the connection to the API is lost after 4 hours, the ESP reboots after 4 hours 15 mins.

Bond246, 2023-11-22:
So since my last changes in reducing load it seems actually much more stable.
Within the last two days there where 6 reboots. Sometimes after ~22 hourse. Sometimes already after 2 hours or 30mins.

In between i checked to use the api instead of mqtt which was an epic fail in my case. After some minutes the api connection is lost then hundreds of reconnects are following and at the end of the day i have to restart all components to get it working again.
I can only speculate the reasons for that. It is very likely that the esphome implementation for node-red is not really stable. But in some cases i thought that the esp32 is struggeling and the api connection is getting fuzzy. And further on the components try to reconnect which increases the struggles.

So at the end of the day this will not solve my problem.

Patrick you wrote that every platform-template section could be disabled. You mean also the sensor components or just specific template components?

Thanks so far!

patrickcollins12, 2023-12-02:
Since this seems to be an issue more with esphome memory and probably using mqtt I suggest joining the esphome discord server where they all hang out and you'll get a lot more ideas.

Closed 2023-12-02.

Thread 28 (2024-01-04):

DHT11 temperature stops updating periodically

chrispontiga, 2024-01-04:
Thanks for sharing this project.  I recently set this up for my new network cabinet, but found that DHT11 temperature sensor stops updating its temp values periodically for 30-45 minutes at a time:

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

Without the temperature input, the fan speed also stays steady, then kicks up to catch up once the temperature updates again.

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

The logs during these states display the DHT11 returns the exact same value repeatedly, without error.

```
[00:05:14][D][sensor:094]: 'Temperature': Sending state 31.80000 °C with 3 decimals of accuracy
[00:05:14][D][sensor:094]: 'Fan Speed (PWM Voltage)': Sending state 85.48193 % with 1 decimals of accuracy
[00:05:14][D][sensor:094]: 'Humidity': Sending state 32.00000 % with 0 decimals of accuracy
[00:05:15][D][sensor:094]: 'Temperature': Sending state 31.80000 °C with 3 decimals of accuracy
[00:05:15][D][sensor:094]: 'Fan Speed (PWM Voltage)': Sending state 85.47862 % with 1 decimals of accuracy
[00:05:15][D][sensor:094]: 'Humidity': Sending state 32.00000 % with 0 decimals of accuracy
[00:05:17][D][sensor:094]: 'Temperature': Sending state 31.80000 °C with 3 decimals of accuracy
[00:05:17][D][sensor:094]: 'Fan Speed (PWM Voltage)': Sending state 85.47533 % with 1 decimals of accuracy
[00:05:17][D][sensor:094]: 'Humidity': Sending state 32.00000 % with 0 decimals of accuracy
[00:05:18][D][sensor:094]: 'Temperature': Sending state 31.80000 °C with 3 decimals of accuracy
[00:05:18][D][sensor:094]: 'Fan Speed (PWM Voltage)': Sending state 85.47204 % with 1 decimals of accuracy
[00:05:18][D][sensor:094]: 'Humidity': Sending state 32.00000 % with 0 decimals of accuracy
[00:05:19][D][sensor:094]: 'Temperature': Sending state 31.80000 °C with 3 decimals of accuracy
[00:05:19][D][sensor:094]: 'Fan Speed (PWM Voltage)': Sending state 85.46874 % with 1 decimals of accuracy
[00:05:19][D][sensor:094]: 'Humidity': Sending state 32.00000 % with 0 decimals of accuracy
[00:05:21][D][sensor:094]: 'Temperature': Sending state 31.80000 °C with 3 decimals of accuracy
[00:05:21][D][sensor:094]: 'Fan Speed (PWM Voltage)': Sending state 85.46545 % with 1 decimals of accuracy
[00:05:21][D][sensor:094]: 'Humidity': Sending state 32.00000 % with 0 decimals of accuracy
[00:05:22][D][sensor:094]: 'Temperature': Sending state 31.80000 °C with 3 decimals of accuracy
[00:05:22][D][sensor:094]: 'Fan Speed (PWM Voltage)': Sending state 85.46216 % with 1 decimals of accuracy
[00:05:22][D][sensor:094]: 'Humidity': Sending state 32.00000 % with 0 decimals of accuracy
[00:05:23][D][sensor:094]: 'Temperature': Sending state 31.80000 °C with 3 decimals of accuracy
[00:05:23][D][sensor:094]: 'Fan Speed (PWM Voltage)': Sending state 85.45885 % with 1 decimals of accuracy
[00:05:23][D][sensor:094]: 'Humidity': Sending state 32.00000 % with 0 decimals of accuracy
[00:05:24][D][sensor:094]: 'Temperature': Sending state 31.80000 °C with 3 decimals of accuracy
```

I have yet to look into the signal integrity on the data line from the DHT11.   But I have tried to swap sensors and got similar behavior.  The only other things I could think of is connecting directly to the header on the ESP rather than the 3-pin JST header, or trying shorter wires to the sensor.

Any other insights would be appreciated.

patrickcollins12, 2024-01-04:
A few theories.

I notice that the update frequency in your log is more frequent than 1 second. Note the update_frequency below. Double check your update frequency is >1.3s, since the DHT11 doesn't have a high refresh rate.

esphome seems to be operating correctly.

Other likely issue is a faulty sensor. Since they're so inexpensive, I'd just try a new sensor.

Maybe wiring issues. You could try adding the recommended resistor to the sensor.

```
  - platform: dht
    pin: GPIO33
    temperature:
      name: "Temperature"
      id: console_fan_temperature
      accuracy_decimals: 3
      ...
    # the DHT11 can only be read every 1s. Use 1.3s to be safe.
    update_interval: 1.3s
```

chrispontiga, 2024-01-05:
Thanks for the reply.  The update interval is set at 1.3s from the original code.  My feeling is that it is a signal integrity issue.  I will occasionally experience warnings as follows:

```
[18:23:14][W][component:214]: Component dht.sensor took a long time for an operation (0.06 s).
[18:23:14][W][component:215]: Components should block for at most 20-30ms.
[18:23:15][D][sensor:094]: 'Temperature': Sending state 31.79999 °C with 3 decimals of accuracy
[18:23:15][D][sensor:094]: 'Fan Speed (PWM Voltage)': Sending state 20.55629 % with 1 decimals of accuracy
[18:23:15][D][sensor:094]: 'Humidity': Sending state 33.00000 % with 0 decimals of accuracy
[18:23:16][W][component:214]: Component dht.sensor took a long time for an operation (0.05 s).
[18:23:16][W][component:215]: Components should block for at most 20-30ms.
[18:23:17][D][sensor:094]: 'Temperature': Sending state 31.79999 °C with 3 decimals of accuracy
[18:23:17][D][sensor:094]: 'Fan Speed (PWM Voltage)': Sending state 20.55299 % with 1 decimals of accuracy
[18:23:17][D][sensor:094]: 'Humidity': Sending state 33.00000 % with 0 decimals of accuracy
[18:23:17][W][component:214]: Component dht.sensor took a long time for an operation (0.05 s).
[18:23:17][W][component:215]: Components should block for at most 20-30ms.
```
I have tried two sensors already with similar results.  I do have one more from the package I can try.  I will also try a 10k pull up since that's minimal effort with some clip leads. I'll provide an update after some tinkering.

chrispontiga, 2024-01-08:
Reporting back with my troubleshooting from this weekend.  I have tried three different DHT11 sensor modules, but all appear to perform similarly where the temperature reading stops updating for some number of minutes.  The 10k pull-up resistor made no noticeable effect, because I think the pull-up may already be included on the PCB of the module I am using.

The last DHT11 module I tried came from a different set ordered from Amazon.  It appeared the HiLetGo-brand appeared to have the highest reviews.  Using this module combined with shorter 3-inch jumpers wires (rather than the longer 6-inch wires I previous used) appeared to have an improved performance.  I'm not sure if it s a better module or the shorter wires was the factor.  But visually, the board looks identical to the no-brand-name modules I first used.

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

At this point I am unsure if the non-updating value is a defect of my board, or if it's actually standard operating function of the sensor.  I would expect that the sensor to continue to provide new values since it reports 3-decimal point accuracy and it's highly unlikely that my networking cabinet is remaining to a thousandth-of-a-degree temperature stable.  But I was thinking that perhaps the DHT11 has a minimum sensitivity and requires a change of several hundredths of a degree before reporting.  I couldn't find any information to confirm with its very limited documentation.  I ordered a BME280 module for delivery tomorrow to see if performs any better.

patrickcollins12, 2024-01-09:
that graph shows it reducing to 88.2 not to 0.0?

My DHT-11

Perhaps your ESP32 board?
Is it really logging during that period or is the ESP32 locked up with memory issues during that period?

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

patrickcollins12, 2024-01-09:
Try reducing the update frequency to every 10 seconds. Try a better sensor like the BME280

https://randomnerdtutorials.com/dht11-vs-dht22-vs-lm35-vs-ds18b20-vs-bme280-vs-bmp180/

Tntdruid, 2024-05-23:
Use a https://esphome.io/components/sensor/sht3xd.html for better data the dh11 is not that great.

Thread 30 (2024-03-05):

3 wire fan

alfadex, 2024-03-05:
Hi, is it going to operate with 3 wire fan? I have two of these and would lik to try. I assume the fourth pin that is missing is tachometer pin,so i will miss the feedback

patrickcollins12, 2024-03-06:
Not really. 3-pin fans are normally +/- and tachometer. You need pwm to have variable voltage (for different speeds).

To use those 3-pin fans, you could use a logic level mosfet to create an external pwm controller.

alfadex, 2024-03-07:
i see,so at 4 pin fan the mosfet is inside the fan. i have to use a moset out of the fan to control with pwm 24 volt fan. In code  you use tachometer pin only for detecting if fan is blocked?

My thought is, let suppose for every cycle of fan we get 1 Hz from tachometer. We test our fan at max voltage and we get  10000 rpm.
If for example we have 30 Celcius, and we need fan to operate at 30%, pwm pin of esp8266 can lower it's output and when our fan reach 3000 rpm and get 3KHz at tachometer pin ,get pwm out stabilized and rpm stay at 3000 rpm. I mean watch tach pin ,and automaticly microcontroller adjust pwm pin  (increase or decrease) output until reach the condition

patrickcollins12, 2024-03-07:
On your first point, that is correct, in a 4-pin, the mosfet is inside the fan. If you want to tinker, learn and solder, buy the mosfet. If not, buy a new 4-pin pwm fan.

In regards to the second paragraph: no you're over thinking it. In fact my project doesn't even use the tach pin. If I did use tach, it would be to detect if the fan was blocked. In this project the main input is voltage 0-12v. Then the output is watching the temperature change. This is done using a pid controller. Tachometer is not needed.

Closed 2024-03-09.

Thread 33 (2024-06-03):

2 powers Input (5v & 12v) [ QUESTION ]

PaulBiod, 2024-06-03:
Hi, thanks for your project, I will try to build it with a noctua fan for my fish tank.
BTW, I have a question : I am planning to use 12v power adapter for the fan and micro usb  cable for the esp32. In this particulary case, should the ground line of the 12v power be also connected to the ground line of the esp32 ?
Thanks

DunklesKaltesNichts, 2024-06-03:
yes

PaulBiod, 2024-06-03:
Thanks for your confirmation

patrickcollins12, 2024-06-15:
I've updated the documentation to make this more clear

Closed 2024-06-15.

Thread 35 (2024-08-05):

Improvments and toughts regarding wiring, components, temperature-sensors and fan min_power

zeus86, 2024-08-05:
First of: great Project. I was about to build basically exactly the same, but for the ventilation of a server cabinet.

I have made some considerations in the past about the requirements for such a project, and compared it to yours, and I came across some noteworthy differences and discrepancies. Some of them could be easily implemented and would lead to improvements, others are just some suggestions, because actively temperature-regulated fans are a super-common requirement with not so many great diy-projects (like this one) that tackle this issue.

1) voltage regulator: an LM2596 can drive alot of power, and is way overkill to power just the ESP and the sensors. Most likely it will burn more power to heat as the ESP itself consumes. Much better suited would be something like this: https://www.amazon.de/gp/product/B07TTH6C3J/ref=ppx_yo_dt_b_search_asin_title?ie=UTF8&psc=1 (you will have to remove the potentionmeter-wheel-metal-part when using a fixed voltage, this unfortunately not documented). This thing is far less powerhungry also. A second one of this in conjunction with a level-shifter can also be used to drive 5v-sensors with ease, and they have a small footprint.

2) your fritzing wiring-image shows, that the TACH-singnals of multiple fans are connected to the same ESP-pin. As far as I know, this is considered bad practice. If you use more than one fan when one is not enough, the better way is just to use off-the-shelf fan-splitters, **_which always route the TACH-Pin only to the first fan_**. They should have thick enough wires to drive plenty of fans. You can easily drive 5+ 120mm fans on full blast without exceeding 1 amp (however this is a different topic for server-grade-fans. They can easily exceed 1A per Fan!). Having pulses from multiple fans on the pin will most likely confuse your hardware. In your code regarding the TACH-Readout you have defined a multiplicator-value to be able to for example "halv" the effective TACH-signal. I am relatively sure, you have the double amount of pulses, because 2 fans are hooked together where they shouldn't be. Identical fans under identical environmental conditions driven by the same PWM-signal are expected to behave the same, so you only need to read the PWM signal once (like how everyone else implements this).

3) your min_power for the fan is 13%. Most fans would stall on this value. For one, your required `min_power` is different when starting from zero compared to "actively regulating up and down" (that is the reason, why most 3d-printer-firmwares give a short 100%-burst for ~0.5secs to a fan when starting up from zero). The widely accepted _sane_ `min_pwm`-value for fans is rather something like ~25%, but this is highly depending on manufacturer and fansize. Some fans require values as high as 35% to run stable.

4) non-pwm-fans: this could also be implemented relatively easy I think. All you need is a step-down-converter that can go up to it's own input-voltage, that you can control by an output-pin of the ESP, and hook the fans to the output of said converter instead of the 12v-rail directly. However, on 2-pin-fans you would loose your feedback-loop (the TACH-Signal), but 3-Pin Fans should work fine (for PC-Fans they are usually DC-controlled then by varying the input voltage of the fans from ~5 to 12 volts. Some Fans may require up to ~7.5V to start.). Most PWM-Fans are also capable of beeing driven by their input voltage (the datasheet sometimes explicitly describes this, for example for some fans from the manufacturer `arctic`), and in some cases it may be desirable to do so.

5) temperature-sensors: You are using the DHT11 here. However, when you want relative humidity, this is great, but It is not really needed here, therefore I'd rather go for DS18B20-Sensors. These are usually, cheaper, more reliable, having a more exact reading and due to the fact, that these are one-wire-sensors, they use a 1wire-bus and more than one sensor can be hooked up all together to the same pin, which simplifies wiring. This would be great for applications with more than one sensor. another advantage is, that they are also available in waterproof form, which greatly increases the possible applications. The only downside (beside no humidity-reading) is the fact, that you most likely have to flash the firmware twice: the first time with a basic-config to get the IDs of the sensor and then flash again with the correct values in the real config, but this is relevant on first install only.

these are just some suggestions, but I think some of them are noteworthy or should find their way into the docs somehow, as many users in the IoT-Space are often not super-experienced with these kind of things, so sane defaults should always apply. In general I think it would greatly increase the value of this project to be a little more versatile in the first place.

however, thanks for this awesome project, it saved me a tremendous amount of work, that's for sure. :+1: .

patrickcollins12, 2024-08-06:
Thanks,

1. hadn't seen those smaller regulators. Do they do 3.3v too? They look good

2. Yeah that was a contribution by someone else, I don't use the tach pin. But agree it should go to different pins.

3. 13% works for my fan under all conditions, nice and short. Each fan needs its own value. Is the documentation not clear in this regard?

4. Yeah a mosfet could easily be used to pwm the whole thing with a 3pin fan. If you look through the recent comments you'll see that some folks need to use a mosfet to get the fan to stop spinning. I feel this is a much not advanced circuit and a 3-pin vs 4-pin fan is typically the same price. I'll update the documentation one day for this not advanced solution.

5. Yah needs a better temperature sensor, esphome doesn't like dht's anymore either. I generally now prefer other sensors.

Glad it worked out for you!

zeus86, 2024-08-06:
>     1. hadn't seen those smaller regulators. Do they do 3.3v too? They look good
they can be powered from 12-24v and they can do 1.8, 2.5, 3.3, 5, 9, 12 Volt using solder-bridges when removing the metal-ring from the poti or something in between using the potentiometer. this makes them perfect for everything that uses 12v as primary power-source. they are dead-cheap, small and awesome. the specs of chinese PCBs are always expected to be exaggregated, but i suppose up to 1 amp should be possible without any issues, which already gets you very far.

>     2. Yeah that was a contribution by someone else, I don't use the tach pin. But agree it should go to different pins.
I still stand by what i wrote, but i actually just looked up some docs, and having 2 countable flanks per revelation seems indeed to be expected, so a multiplier of 0.5 should always be correct.

>     3. 13% works for my fan under all conditions, nice and short. Each fan needs its own value. Is the documentation not clear in this regard?
just testing with some old server-fans...as long as they have input voltage, they run at least with ~34% PWM regardless of what is beeing set, and they also refuse to turn off :shrug: (i am beginning to believe this is to be expected for explicit server-fans, to gurantee a minimal amount of airflow, because many PCI-cards in servers like high-speed nics and raidcontrollers would otherwise cook themself to death very quickly without external airflow).
>     4. Yeah a mosfet could easily be used to pwm the whole thing with a 3pin fan. If you look through the recent comments you'll see that some folks need to use a mosfet to get the fan to stop spinning. I feel this is a much not advanced circuit and a 3-pin vs 4-pin fan is typically the same price. I'll update the documentation one day for this not advanced solution.
:+1:
>     5. Yah needs a better temperature sensor, esphome doesn't like dht's anymore either. I generally now prefer other sensors.
sometimes i think about just using a thermistor, because they don't block the esp-watchdog so drastically, all DHTs and Dallas-sensors i tested do unfortunately produce warnings like those:
```
[07:06:40][D][sensor:093]: 'Temperature': Sending state 28.73952 °C with 1 decimals of accuracy
[07:06:40][D][sensor:093]: 'Humidity': Sending state 46.00000 % with 0 decimals of accuracy
[07:06:40][W][component:237]: Component dht.sensor took a long time for an operation (107 ms).
[07:06:40][W][component:238]: Components should block for at most 30 ms.
```
>
> Glad it worked out for you!
be sure it has xD

patrickcollins12, 2024-08-19:
I added a 2nd tach pin input to the console-fan.yaml for clarity.

Closed 2024-08-19.

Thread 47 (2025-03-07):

My fan still keeps turning

ZhiqiKou, 2025-03-07:
I connected the 12V and 3.3V ground cables, but my fan still kept turning。

patrickcollins12, 2025-03-09:
see this thread and this recommended solution: https://github.com/patrickcollins12/esphome-fan-controller/issues/17#issuecomment-2210574948

ZhiqiKou, 2025-03-09:
> see this thread and this recommended solution: [#17 (comment)](https://github.com/patrickcollins12/esphome-fan-controller/issues/17#issuecomment-2210574948)
Thank you, I checked this question, I am a novice, and do not have other equipment, such as what type of diode should I buy?

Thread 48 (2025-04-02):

Finding the perfect PID-spot

djjoakim, 2025-04-02:
Hey!
First of all, I really love this project - this is exactly what I’ve been dreaming about for ages, so big thank you for taking your time making this!

That being said, I have some problems with the fine-tuning of my PID…
I have a pretty special solution, I have a cabinet that’s in a room where the surrounding temperature increases/decreases a lot, so I need to find a perfect PID band that goes smooth all the way, no matter if the surrounding temperature is 5c or 20c.

Soo, I have tried some different deadband settings, and KP, KI settings - and I got it pretty smooth, but then I started seeing this ”spikes” in the output value, the output value sends 0% for 2s here and there, and I can’t figure out why..
So I figure, hey - let’s try the default (aka yours) PID and deadband settings, and as you can see in the log - it started behaving more up and down after that. (My change was made 23:00).

The previous settings I had before changing to the defaults where;

KP - 0.4
KI - 0.001
KD - 0.0

Deadband low - 2.0
Deadband high - 0.5
Ki multiply - 0.01

Love to hear your thoughts about this.
Thanks so much in advance!

Ps, I’ve translated the names to Swedish so in the diagram, the colours means;

Dark blue - actual temperate
Light blue - cooling
Yellow - taget temperature
Red - just another temperature sensor in the cabinet (doesn’t affect the regulator)
Green - room temperature

Thanks again!

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

kimfr, 2025-04-03:
Are you perhaps using DS18B20 temp. sensors?
In my current setup, as soon as I add 2 (or more) DS18B20 on the same one-wire - I get a similar issue. Been doing some research and found that this is actually an issue in the ESP code - which hasn't been resolved yet.

djjoakim, 2025-04-03:
> Are you perhaps using DS18B20 temp. sensors? In my current setup, as soon as I add 2 (or more) DS18B20 on the same one-wire - I get a similar issue. Been doing some research and found that this is actually an issue in the ESP code - which hasn't been resolved yet.

Yes, I have 2 DS18B20 sensors in the same one wire! Oh, this makes sense. I will try to remove the second temp sensor to see if it disappears.
Thank you so much in advance for this information!

kimfr, 2025-04-03:
I was also thinking it might be a power issue so I was going to try and power the DS18B20 from the 5V output of the ESP (according to spec you can) - just haven't had time......

djjoakim, 2025-04-08:
> I was also thinking it might be a power issue so I was going to try and power the DS18B20 from the 5V output of the ESP (according to spec you can) - just haven't had time......

I power mine through the USB 5v.

I tried removing one of the DS18B20 sensors but I keeps dropping :( maybe it’s something to do with the update time? What time do you have?

djjoakim, 2025-04-09:
> Are you perhaps using DS18B20 temp. sensors? In my current setup, as soon as I add 2 (or more) DS18B20 on the same one-wire - I get a similar issue. Been doing some research and found that this is actually an issue in the ESP code - which hasn't been resolved yet.

I think I was too fast answering my self in the last post, I still had the second sensor connected (just removed the DATA cable) and of course, it was still in the code.

So - now I have removed all the cables to the sensor and also removed it from the code and so far, it’s no spikes at all.
Thank you so much for the help!

Closed 2025-04-09.

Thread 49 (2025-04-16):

Fan on 100% Speed dont have the 100% RPM

bastiitsab, 2025-04-16:
Hello and thanks for this nice project!

 I am using three of these fans:  [ARCTIC P12 PWM PST 120x120x25 ](https://www.alternate.de/ARCTIC/P12-PWM-PST-120x120x25-Geh%C3%A4usel%C3%BCfter/html/product/1856949). They are connected with the built-in Y-Cable, so only one cable goes to the ESP32.
When the fan speed PWM voltage is at 100%, the RPM displays only 1644RPM (instead of the possible 1800RPM). In initial testing with one fan, it reached nearly 1800RPM.

Is it possible to set the 100% higher to achieve more RPM?

patrickcollins12, 2025-04-17:
this could be one of a few issues:
1. that could be the max speed of the fan.
2. insufficient power
3. a software issue with the esphome fan controller.

You would need to test these indpendently.
1. rewire it to go directly into 12v rather than via PWM
2. do you have a power station to increase voltage?
3. put a multimeter between ground and the pwm out pin... it should be 3.3v when at max power.

McDive, 2025-04-22:
first of all I need to thank Mr. Collins for this project. Great, easy to implement and works fine so far. I have the same issue with the FAN RPM. But this I will ask an other time. I like to control 2 FAN's PWM(Speed) independent. But I don't know if the PID Controller can control to FAN's   ? any hint would be nice....I found this subject on Git but can't find it anymore. I think Mr Collins solved my question

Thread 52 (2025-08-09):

While hooked up to Noctua NF-A14x25 G2 PWM Sx2-PP my ESP32 module fried

rostar99, 2025-08-09:
I am trying to cool my server closet with two 140mm Noctua on the top of the rear wall exhaust vent. I purchased these ESP32 modules https://a.co/d/8dxVeGl which include an expansion board. I powered the ESP32 board with the expansion board dcv input (which can take in 12v) and split the 12v to power the fans. I powered the DHT11 board off the 3.3v output on the expansion board. I wired everything up and poof the ESP32 module went up. Checked all the grounds and wire leads and board voltages and the second ESP32 module (with a second expansion board) went poof. I disconnected the boards and ran the fans alone and the fans work at 100% and when I ground the PWM pin they stop as expected. I noticed that when the fans are running I can measure 3.3 -2.5 vac  coming off the PWM pin. I purchased new ESP32 Freenove boards https://a.co/d/e67Bpqc  but have put have project on hold till I can figure out why the original ESP32 boards fried. Powering the ESP32 via the dc port on the expansion board works fine on the third and final board but so did the other two before the magic smoke release. Any pointers or suggestions to troubleshoot or alter the original circuit would be appreciated.

Thank you

patrickcollins12, 2025-08-09:
12v is finding its way directly into the ESP32 module and frying it. It cannot handle more than 3.6v. I haven't used that expansion board before, but assuming it works as advertised, then it is how you're wiring it together.

Would need to see a diagram or photo to help further.

rostar99, 2025-08-10:
Here is a diagram of what I tried to do with the expansion board and ESP32. I did check all the ground and power pins on the expansion board and the ESP32 module (5v 3.3v on expansion and 3.3v on ESP32 itself) and the all read correct voltage when tested with my multimeter when powered on. Only shorted when I hooked up the fans and dht11 to the pins. Additionally, I had not successfully flashed the board yet as I am having trouble getting it into download mode.
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

rostar99, 2025-08-11:
As a follow up I was able to get the last one into download mode but I get a TX pin error so still not programmable. I am sending them back for full replacement (glutton for punishment) to try again from scratch. I am still puzzled how just hooking up the fans, dht11 as I diagrammed and powering it up caused the release of magic smoke. I thought if the ESP32 module was not programmed the fans would run at full speed with no control?  I have emailed Noctua to confirm these particular fans can be controlled on a ESP32 PWM 3.3v output.

patrickcollins12, 2025-08-11:
I can't see anything wrong with your diagram.

It's possible although unlikely, that you've fried your board or more likely the fans and they're accidentally passing 12v back through the tach pin. I've had that problem before with fans... if they get overloaded the circuit could be shorted. Easy to test though, put a multimeter between the tach pin and the ground. Or just unplug the tach pins.

Esp32's are cheap. Don't despair. You need 30 of them anyway... for... projects.

By the way, it's possible but unlikely that the fans don't support 3.3v. They're PWM and rely on the frequency not a high voltage.

patrickcollins12, 2025-08-12:
I'd go back to basics. Plug the esp32 in directly using my original design. Just use a regular USB plug for now into the ESP32. Then use that process to whittle down the source of your error.

rostar99, 2025-08-12:
Replacement units ESP32 arrive today and I will set up powered by USB as a test set up and go from there as you suggest. I will update tomorrow with result. Thanks again.

rostar99, 2025-09-05:
When I tested one of the replacement ESP32 boards (powered by the expansion board) the expansion board shorted taking out the connected ESP32 board.  I believe my earlier problems where related to prior live testing on the expansion boards. When the expansion board fails it sends full input voltage to the ESP32 board, killing it. So the problem was caused by a combination of user error and poor failure design on the expansion board. I sucessfully set up my two noctua fans using the ESP32 Freenove board powered by a buck converter without a problem.

rostar99, 2025-09-05:
Thanks for your help and sorry about the late follow up post on the resolution.

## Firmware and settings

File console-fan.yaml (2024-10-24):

substitutions:
  friendly_name: Console Fan

esphome:
  name: console-fan

# Throttle writing parameters to the internal flash memory to reduce ESP memory wear / degradation
preferences:
  flash_write_interval: 15min

 
#########################
# ESP32 AND NETWORK SETUP

esp32:
  board: nodemcu-32s
  framework:
    type: arduino

# pid climate log update is noisy, dial it back to warn
logger:
  level: DEBUG
  logs: 
    climate: ERROR
    dht: WARN

# default HA integration, OTA updater and backup http web portal
api:

ota:
  - platform: esphome
  
wifi:

  # Read the wifi/pass from secrets.yaml:
  # wifi_ssid: "My Wifi XX"
  # wifi_password: "XXXXXXX"
  ssid: !secret wifi_ssid
  password: !secret wifi_password

number:

  ## OPTIONAL:
  # RECEIVE KP, KI and KD parameters from input_text.kx helpers in 
  # Home Assistant. See the PID controller below
  # These helper values will get saved to flash thus permanently over-riding 
  # the initial values set in the PID below.

  # KP
  - platform: template
    name: kp
    icon: mdi:chart-bell-curve
    restore_value: true
    initial_value: 0.3
    min_value: 0
    max_value: 50
    step: 0.001
    optimistic: true
    set_action: 
      lambda: |- 
        id(console_thermostat).set_kp( x );

  # KI
  - platform: template
    name: ki
    icon: mdi:chart-bell-curve
    restore_value: true
    initial_value: 0.0015
    min_value: 0
    max_value: 50
    step: 0.0001
    optimistic: true
    set_action: 
      lambda: id(console_thermostat).set_ki( x );

  # KD
  - platform: template
    name: kd
    icon: mdi:chart-bell-curve
    restore_value: true
    initial_value: 0.0
    min_value: -50
    max_value: 50
    step: 0.001
    optimistic: true
    set_action: 
      lambda: id(console_thermostat).set_kd( x );

  # Set threshold low
  - platform: template
    name: Deadband Threshold Low
    icon: mdi:chart-bell-curve
    restore_value: true
    initial_value: -1.0
    min_value: -20
    max_value: 0
    step: 0.1
    optimistic: true
    set_action: 
      lambda: id(console_thermostat).set_threshold_low( x );

  # Set threshold high
  - platform: template
    name: Deadband Threshold High
    icon: mdi:chart-bell-curve
    restore_value: true
    initial_value: 0.4
    min_value: 0
    max_value: 20
    step: 0.1
    optimistic: true
    set_action: 
      lambda: id(console_thermostat).set_threshold_high( x );

  # Set ki multiplier
  - platform: template
    name: Deadband ki Multiplier
    icon: mdi:chart-bell-curve
    restore_value: true
    initial_value: 0.04
    min_value: 0
    max_value: .2
    step: 0.01
    optimistic: true
    set_action: 
      lambda: id(console_thermostat).set_ki_multiplier( x );

text_sensor:

  # Send IP Address
  - platform: wifi_info
    ip_address:
      name: $friendly_name IP Address

  # Send Uptime in raw seconds
  - platform: template
    name: $friendly_name Uptime
    id: uptime_human
    icon: mdi:clock-start

sensor:

  # Send WiFi signal strength & uptime to HA
  - platform: wifi_signal
    name: $friendly_name WiFi Strength
    update_interval: 60s

  # This is a bit of overkill. It sends a human readable 
  # uptime string 1h 41m 32s instead of 6092 seconds
  - platform: uptime
    name: $friendly_name Uptime
    id: uptime_sensor
    update_interval: 60s
    on_raw_value:
      then:
        - text_sensor.template.publish:
            id: uptime_human
            # Custom C++ code to generate the result
            state: !lambda |-
              int seconds = round(id(uptime_sensor).raw_state);
              int days = seconds / (24 * 3600);
              seconds = seconds % (24 * 3600);
              int hours = seconds / 3600;
              seconds = seconds % 3600;
              int minutes = seconds /  60;
              seconds = seconds % 60;
              return (
                (days ? to_string(days) + "d " : "") +
                (hours ? to_string(hours) + "h " : "") +
                (minutes ? to_string(minutes) + "m " : "") +
                (to_string(seconds) + "s")
              ).c_str();

  # Read the Tacho PIN and show measured RPM as a sensor (only with 4-pin PWM fans!)
  # See instructions here: https://esphome.io/components/sensor/pulse_counter.html
  - platform: pulse_counter
    pin: 
      number: GPIO25   # Connect to any input PIN on the ESP
      mode: INPUT_PULLUP
    unit_of_measurement: 'RPM'
    id: fan_speed
    name: $friendly_name Fan Speed 1
    accuracy_decimals: 0
    filters:
      - multiply: 0.5  # Depending on how many pulses the fan sends per round - should be 0.5 or 1 - try...

  - platform: pulse_counter
    pin: 
      number: GPIO26   # Connect to any input PIN on the ESP
      mode: INPUT_PULLUP
    unit_of_measurement: 'RPM'
    id: fan_speed_2
    name: $friendly_name Fan Speed 2
    accuracy_decimals: 0
    filters:
      - multiply: 0.5  # Depending on how many pulses the fan sends per round - should be 0.5 or 1 - try...
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

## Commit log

2022-02-10 send every 1. tried max filter didn't help much
    [console-fan.yaml]
2022-05-18 updated circuit image
2022-05-18 updated image
    [breadboard.fzz]
2023-01-28 Add pulse-counter to read fan RPM
    If you'd like to include this let me know and I'll add some info to the readme as well...
2023-02-04 Update console-fan.yaml
    Throttle writing parameters to the internal flash memory to reduce ESP memory wear / degradation
2023-02-04 Update README.md
    Added info for TACH pin...
2023-02-05 with tachometer
    [breadboard.fzz]
2023-03-11 pin change
2023-03-14 changed fan tach to use 2 pins
    [breadboard.fzz]
2023-05-21 fix tach color in wiring digram
    [breadboard.fzz]
2023-05-24 Update README.md to include mosfet instructions
2024-03-08 Update README.md
    3pin fan description
2024-06-08 Update README.md
    Added common troubleshooting on wiring
2024-06-08 Update README.md
    NOT joining grounds
2024-08-19 Update console-fan.yaml
    Added tach pin speed 2
2024-09-01 Fixed bug "ota" config has changed.
    [console-fan.yaml]
2025-01-13 Update README.md
    added jumper wires.
2025-01-13 jumper wires added
